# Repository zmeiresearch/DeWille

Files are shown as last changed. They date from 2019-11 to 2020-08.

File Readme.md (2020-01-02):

# DeWille - A modular Audio DAC platform

DeWille is designed to be a set of building blocks for audio DACs. Currently, the following 'blocks' are planned:
* A Base board - Power supplies, interconnects, physical board support
* A Control board - Input selection, reclocking, other digital signal processing
* A PCM1792 DAC board
* An I/V converter board

## Features:
### Inputs/Outputs and interface
* Supports multiple input and output formats:
  * I2S, Left-justified and right-justified PCM
  * S/PDIF, optical and coaxial
  * (Maybe) DSD
* Supports at least 24-bit@192kHz
* Configurable asynchronous reclocking with a FIFO
* Provision for USB support based on either XMOS or Amanero COTS board 
* Provision for Bluetooth audio support
* Provision for playback via WiFi
* Provision for an (oled?) display

### Analog side
* DAC section based on PCM1792
* Supports DAC Mono mode
* Supports PCM1792(4) in NOS mode (inspired by DDAC)
* CCS for PCM1792 Iref
* Supports multiple I/V Converters
* Low-noise power supply for both analog and digital sections

## Design considerations

### Control board
The control board is by far the most complex one in the set. It implements input selection, reclocking as well as all
the signal conversion and processing required to drive the DACs. Several distinct components work together to do this 
- an FPGA, a clock generator block and an MCU module. All the blocks are connected to each other via an SPI bus, with 
the MCU acting as master. The SPI bus also connects to the two DAC boards, allowing on-the-fly reconfiguration as 
required.

#### Hardware Design
* **FPGA**
The FPGA is the one actually doing all the signal manipulation and transformation work. It takes I2S data (PCM and DSD
planned for the future), does the actual reclocking (if told to do so) and outputs I2S (DSD planned for the future) to
the two separate DAC board.

The choice of an FPGA has been a difficult one. First and foremost, an SMD(QFP) package is a must. I have no problem
hand-soldering 0402 components, but I have neither the equipment nor the expertise to handle BGAs reliably. This 
alone limits the choice to basically Xilinx Spartan 3 and some Lattice families. (Intel and Microchip not considered
for different reasons). With ISE 14.7 the last one supporting Spartan 3 and the family NRND for new designs in general
I settled on Lattice, LFXP2-8E-5TN144 in particular. MachXO2 is also an option for a future redesign.

There is an on-board 8-bit wide SRAM chip, with a maximal capacity of 8MBit. Possiblity for a future update is either 
increasing the SRAM size (larger buffer) or increasing the datapath width (better throughput/lower latency).

The FPGA can also be programmed and debugged using the integrated FT2232 interface or the standard Lattice JTAG
connector. If using the FT2232, the second channel is connected to two FPGA pins that could implement a debug UART.

* **Clock generator**
The clock generator block is implemented with two oscillators (at 24.576MHz and 22.5792MHz) and an Si5344 multiplexer,
jitter reduction and clock output buffer circuit. Two of the clock outputs go directly to the DAC boards via either 
the pin header or a dedicated SMA interconnect, while the third is distributed to the FPGA to drive the reclocking 
internally. This clock arrangement is guaranteed to introduce a phase margin between the master clock and the bit/data
clock, but the PCM1794(2) and, in theory, all other DACs that require a System/Master clock do not need a specific 
relation between the two, as long as it remains a fixed one.
Regular oscillators are used rather than TCXOs because the actual frequency and long term drift are not that important 
to the sound quality and the Si5344 performance dominates the short-term jitter performance 

Possibility for a future enchancement is to also route the SCK input from the two I2S inputs to the remaining two
Si5344 inputs to allow source-synchronous operation as well.

* **MCU**
A ESP32-DevKit module was selected for the main MCU. The rationale to use an off-the-shelf MCU module is two-fold.
_First,_ by using an COTS hardware module with a well-established and easy to use software ecosystem behind it, I'll
be able to focus on the signal processing part of the project.
_Second,_ it will be much easier to implement other functionality in the future - OTA updates, including the FPGA 
bitstream, WiFi streaming, Alexa/Google home integration, etc.

* **Power Supply**
The control board takes a single, 5V regulated power supply. There is an on-board protection by means of a polyfuse
and a 6.8V Transil. This is powering a total of 6 voltage regulators:
  * +3V3_IO and +3V3_FPGA -  used for FPGA I/O ports, Debug/Program USB and on-board LEDs
  * +1V2_FPGA - FPGA Core supply
  * +3V3_CLKOUT - Clock outputs of Si5344
  * +3V3_VDDACLK and +1V8VDDCLK - analog and digital sections of Si5344 respectively
  * +3v3_VDDOSC - the two crystal oscillators
  * The on-module voltage regulator in the ESP32 module.

### DAC PCM1794(2)

### Base Board
The base board is responsible for physically carying the different modules together, connecting them electrically and
providing all the required power supplies. In addition, it implements input signal galvanic isolation to limit the harm
in case of failure of signal sources.

* **Power supply**
The base board takes a 220/110VAC mains supply and has two separate sets of transformers. Either 50VAC toroidal power
transformers or PCB-mounted sealed ones can be used. One of the transformers is providing the +5V regulated supply
necessary for the digital part of the schematic, while the other provides a +/- 15V supply.

All three +5V power supplies are filtered and regulated using a hybrid capacitance multiplier/regulator circut. In
addition, there are also two 3.3V regulators for the input galvanic isolators - an LDO for the 'in' side and a 
DC-DC for the 'out' side.

### I to V module
**WiP/TBD.** Assumed to have the same dimensions as the DAC module while creating the Base board.

## FAQ
* **Is DeWille HiFi/Audiophile grade?**
  No. It will just sound good.
* **Where does the name DeWille come from?**
  It was inspired by a [Frey Wille](https://www.freywille.com) scharf that happened to be around while thinking about
  a name for the project.

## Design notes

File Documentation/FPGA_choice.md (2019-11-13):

Requirements:
To be hand-solderable (i.e. no BGA!)
At least 70 IOs (40 IOs for 1MB/16bit RAM, 5 for MCU interface, 4 audio interfaces x 4 IOs each, 5 misc)
Development tools to be easily available.

Initial requirements opted for a much smaller pin count, as external RAM was not required. Choice went to LCMXO2-1200 in a 32-pin QFN package. It proved impossible to find any documentation listing pinouts, will all references either dead or requiring to install Lattice Diamond. 

After re-evaluating the requirements, it was decided to include an external RAM memory for a FIFO inplementation with a sufficient depth. This bumped the requirements for pin count to 70I/Os at least, as 40 extra lanes were required and requiring additional logic gates for the implementation as well. Thus, a Xilinx XC3S100 in a TQFP-100 package was selected. 

However, Spartan 3 is supported only by ISE 14.7, which, in turn is not supported on Win10. All the parts that are supported by the newer toolset appear to be BGA, bringing back the preference to Lattice (Intel out of question due to bad sentiment). So far, LFXP2-8E-5TN144C seems to be the winner, offering a good balance between logic density, timing and price

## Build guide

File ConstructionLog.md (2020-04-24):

# This is an annotated account of the build&construction activities around DeWille

## 26-Nov-2019
*DeWille_Control_Rev_1_0* and *DAC_PCM1794_Rev1_0*, rev. #7dc6edd, sent to 
[SeeedStudio](https://www.seeedstudio.com/fusion_pcb.html) for fabrication. Total cost is $74.20:
* $4.90 for 10 pcs of DAC_PCM1794
* $49.90 for 10pcs of DeWille_Control
* $19.40 shipping

## 13-Dec-2019
Parts for first two prototypes ordered from [Comet](http://www.comet.bg) and [Mouser](http://www.mouser.bg)

## 17-Dec-2019
Parts arrived

## 02-Jan-2020
Control and DAC Boards arrived
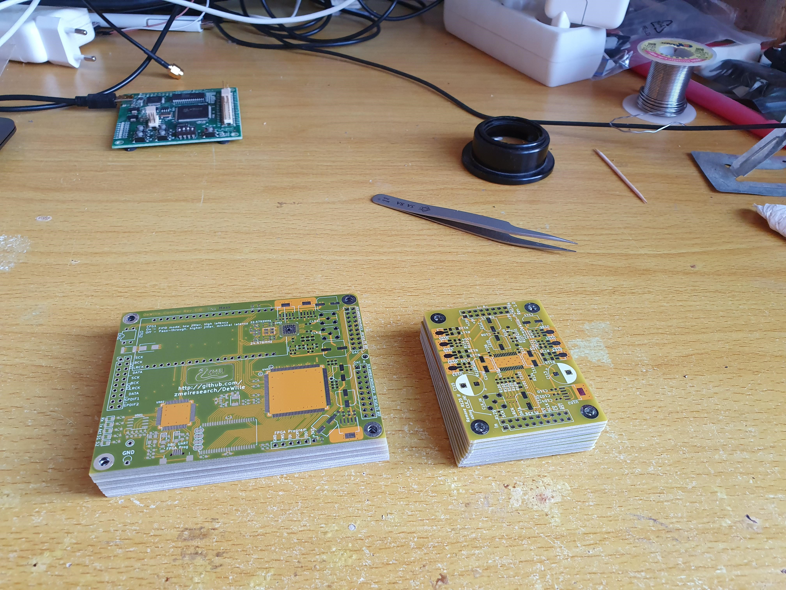
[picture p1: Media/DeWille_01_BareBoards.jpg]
Bare Boards


## 08-Jan-2020
Started soldering one Control board.
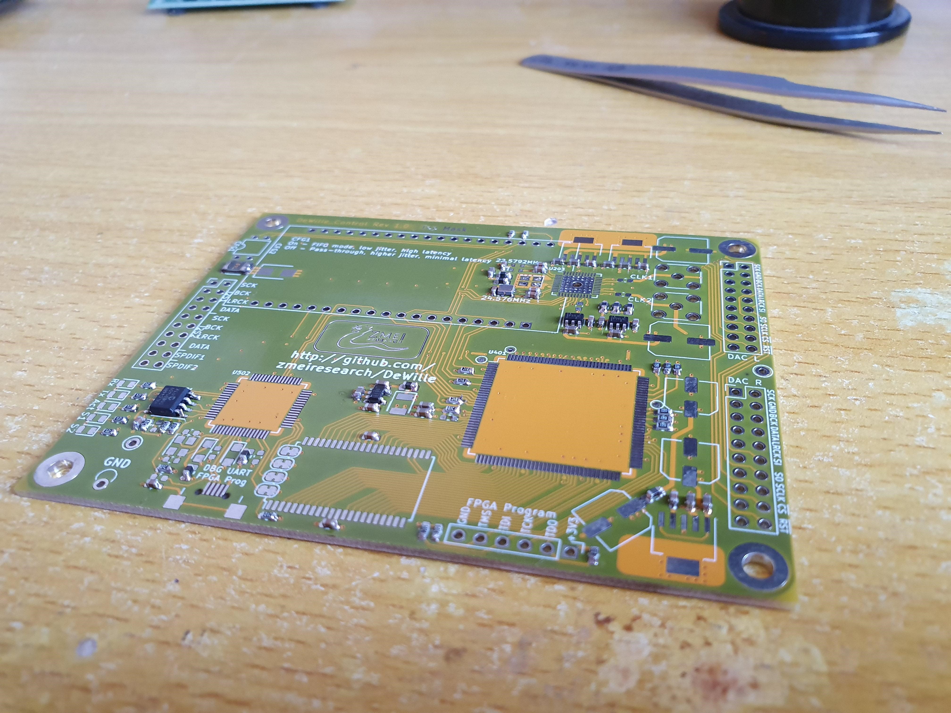
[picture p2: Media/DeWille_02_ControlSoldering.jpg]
Control Soldering


## 09-Jan-2020
One BaseBoard sent to [Selectra](http://www.selectrapcb.com) for fabrication

## 11-Jan-2020
Control board soldering complete, with the exception of the FPGA, the Si5344 and the non-washable components (SMA 
connectors and DIP switces). Applied power and verified that all supply voltages are correct. Gave a final wash
to the Control board to clean flux residue.

## 12-Jan-2020
Soldered two DAC boards without the DAC chips. Applied power and verified supply voltages.
Soldered the rest of the components on the Control board.
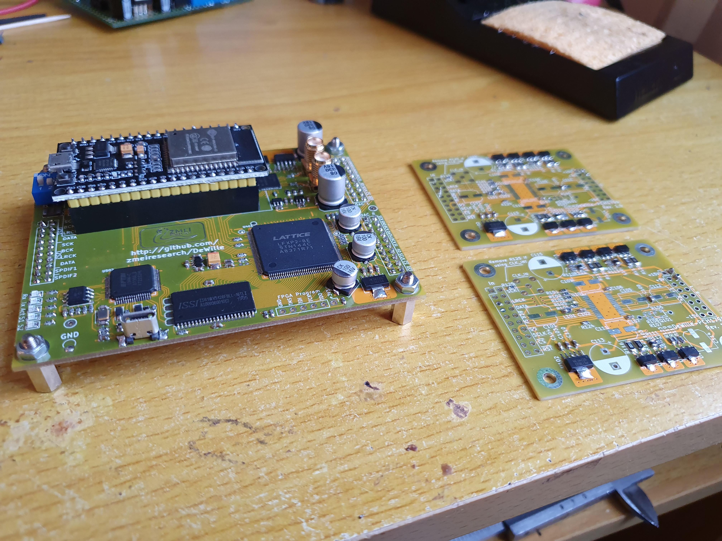
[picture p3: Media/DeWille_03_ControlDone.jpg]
Control done


## 25-Jan-2020
BaseBoard received from PCB house

## 2-Feb-2020
Soldered BaseBoard components without transformers and big filtering caps. Powered the +5V regulator from bench
supply, got +4.6V output due to error in schematic (R217/R220 divider not taken into account when calculating
reference voltage). Changed R212 to 1.5k and got +4.99V output into a 56 Ohm dummy load, verified that regulator
is stable with scope and left it for ~2 hours. With a 6.6 Ohm load(little less than 1A current) and no heat-sink,
the regulator transistor experienced a non-destructive thermal runaway (but the output voltage increased, so 
it may have potentially damaged the rest of the circuit) - probably need to reconsider the topology for later.

Because of the above, decided to use the analog supplies in capacitance multiplier mode rather than regulator, so 
removed U201, U202 and the resistors around them.
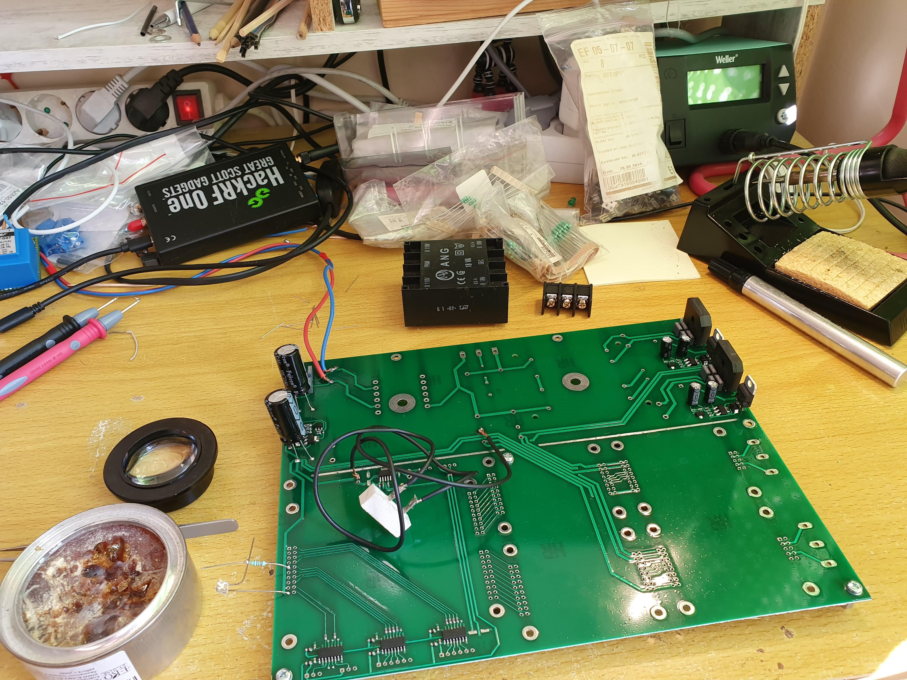
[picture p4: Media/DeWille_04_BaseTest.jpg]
Base test


## 5-Apr-2020
Some work on the software for the Control board:
 * Settled on using the Espressif-supplied version of FreeRTOS along with [PlatformIO](https://platformio.org/) 
 as a base for the software.
 * Implemented a (mostly) platform-independent logger and routed it through the secondary UART of FT2232
 * Implemented a SPI bus arbitrator, to allow multiple components to communicate with the multiple slaves on the
 SPI bus.
 * Added Si553x-specific pseudo-driver that allow read/write of specific registers and bulk set-up based on. 
 [ClockBuilderPro](https://www.silabs.com/products/development-tools/software/clockbuilder-pro-software) exports
 * Added a small script (SiMerge.py) to automatically merge multiple CBP exports into a single file.

After some trial&error, Si5344 started outputting clock signals. Next I'm shifting to the FPGA to try and get some
actual audio data going.

## 20-Apr-2020
After spending some time in Lattice Diamond, I've decided to switch as much as possible to an open/free toolset. All
FPGA modules will be developed in simulation, using Icarus [Verilog](http://iverilog.icarus.com/) &
[GTKWave](http://gtkwave.sourceforge.net/). Only the final synthesis and verification will be done within Diamond (or
another tool if/when the FPGA is changed).
So far, a dummy (as in not doing much) SPI slave module is implemented, along with a testbench and support
infrastructure - I am able to execute the testbench and check the signals/data visually in a single command

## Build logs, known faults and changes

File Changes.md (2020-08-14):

# Future changes

## DAC_PCM1794_Rev1_0
* Change SMA connector with bigger pads
* Polygon fill on the top layer (better color!)
* Add GND and power testpads
* Consider strategic cuts in the GND polygon to separate GND current flow
* The JFET pin-out has Source and Drain swapped
* The JFET CCS circuit is wrong

## DeWille_Control_Rev_1_0
* Change SMA connector with bigger pads
* Use logo with silk-screen
* Add bottom silk screen
* Remove mask at bottom layer of Si5344
* Align GND bottom left testpad silk
* Polygon fill on the top layer (better color!)
* Change footprint for 2.5x2 oscillators for better solderability
* Change footprint for Si5344 to have longer pads
* Increase via diameter below Si5344
* Add silk text to the two TH testpads - 3.3 and far right GND
* Switch to 30pin ESP32 DevKit
* Add a protection diode + jumper for ESP32. Current ESP board connects Vin
  directly to Vusb, which is convenient during development, allowing stand-
  alone operation, but may possibly damage board and/or computer if power
  is applied on both sides
* Move nCS_FPGA and FGPA_DONE away from the UART0 pins
* Check why RX LED is on when the ESP is transmitting and vice versa
* Increase resistors on Green LEDs
* Move FPGA (and maybe the clock as well) to the other SPI bus so that 
  hardware SPI CS can be used
* Fix the ESP32 symbols mix-up (pin25 duplicated, 36 missing)
* Route nINTR Si5344 output to ESP32 so that status polling is not needed
* Make the Clock chip and power supply heat-sinks larger
* Move CS_DACL away from pin35 - input-only 

## DeWille_Base_Rev_1.0
* The GNDD polygon is not correctly manufactured. Check with PCB house whether
  the issue is with the gerbers or with them
* Add Silkscreen and Zmei Research logo
* Remove silkscreen from Top GND tracks separating transformers and the rest of
  the circuit
* Change big filtering capacitors to snap-in ones
* Mark R220 DNP or change R212 to 1.5k
* Add LEDs indicating power status
* Make input connections for I2S fit the standard XMOS/BT board layouts

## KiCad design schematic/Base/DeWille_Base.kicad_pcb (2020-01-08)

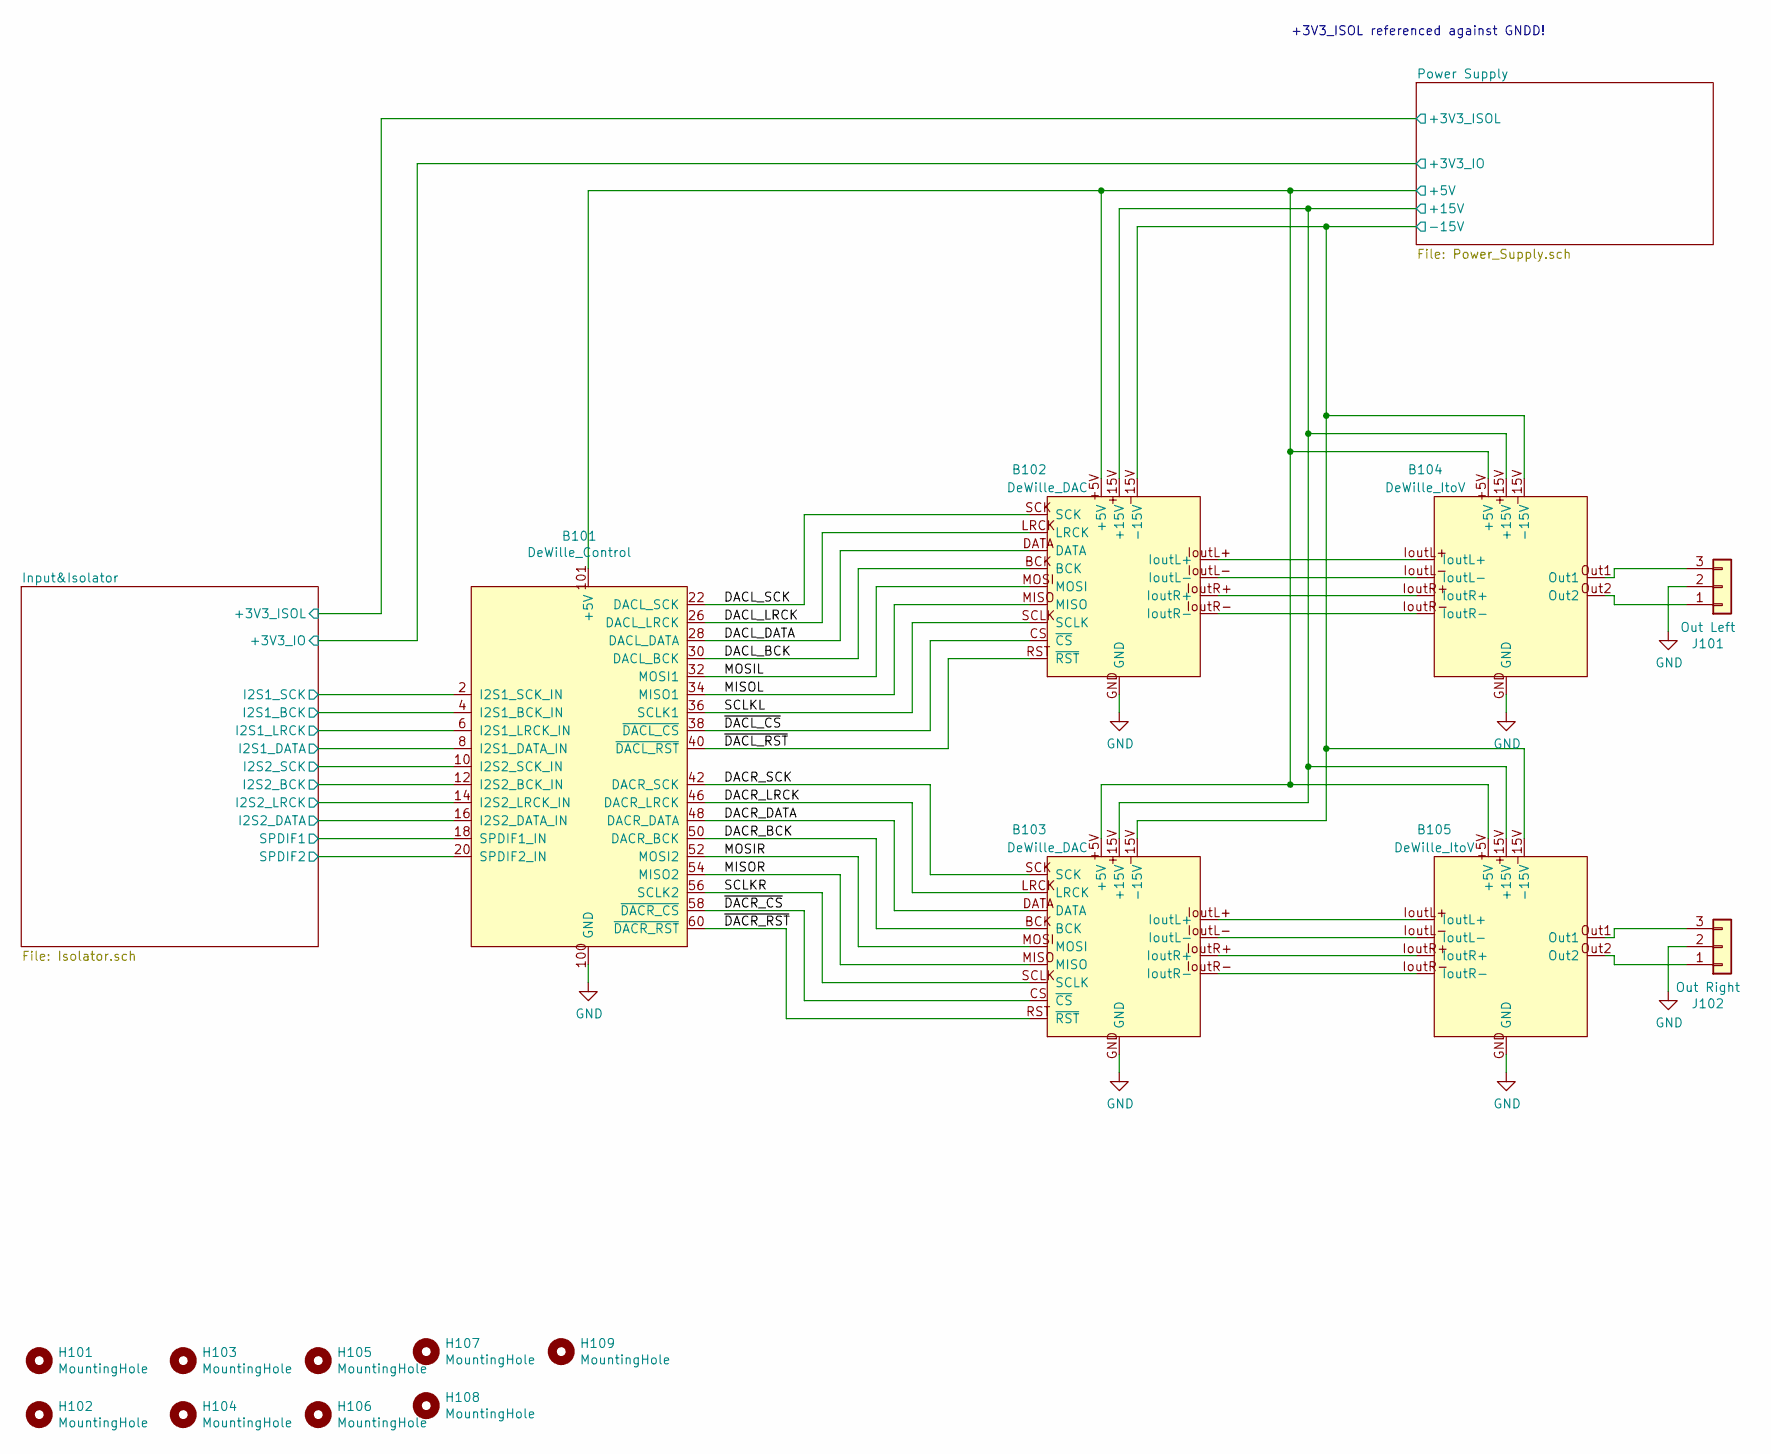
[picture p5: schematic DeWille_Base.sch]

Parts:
B101: DeWille_Control
B102, B103: DeWille_DAC
B104, B105: DeWille_ItoV
H101, H102, H103, H104, H105, H106, H107, H108, H109: MountingHole; MountingHole_3.2mm_M3_Pad
J101: Out Left; TerminalBlock_Dinkle_DT-55-B01X-03_P10.00mm
J102: Out Right; TerminalBlock_Dinkle_DT-55-B01X-03_P10.00mm

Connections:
/DACL_BCK: B101.30 (DACL_BCK), B102.BCK
/DACL_DATA: B101.28 (DACL_DATA), B102.DATA
/DACL_LRCK: B101.26 (DACL_LRCK), B102.LRCK
/DACL_SCK: B101.22 (DACL_SCK), B102.SCK
/DACR_BCK: B101.50 (DACR_BCK), B103.BCK
/DACR_DATA: B101.48 (DACR_DATA), B103.DATA
/DACR_LRCK: B101.46 (DACR_LRCK), B103.LRCK
/DACR_SCK: B101.42 (DACR_SCK), B103.SCK
/Input&Isolator/I2S1_BCK: B101.4 (I2S1_BCK_IN); also elsewhere on the board
/Input&Isolator/I2S1_DATA: B101.8 (I2S1_DATA_IN); also elsewhere on the board
/Input&Isolator/I2S1_LRCK: B101.6 (I2S1_LRCK_IN); also elsewhere on the board
/Input&Isolator/I2S1_SCK: B101.2 (I2S1_SCK_IN); also elsewhere on the board
/Input&Isolator/I2S2_BCK: B101.12 (I2S2_BCK_IN); also elsewhere on the board
/Input&Isolator/I2S2_DATA: B101.16 (I2S2_DATA_IN); also elsewhere on the board
/Input&Isolator/I2S2_LRCK: B101.14 (I2S2_LRCK_IN); also elsewhere on the board
/Input&Isolator/I2S2_SCK: B101.10 (I2S2_SCK_IN); also elsewhere on the board
/Input&Isolator/SPDIF1: B101.18 (SPDIF1_IN); also elsewhere on the board
/Input&Isolator/SPDIF2: B101.20 (SPDIF2_IN); also elsewhere on the board
/MISOL: B101.34 (MISO1), B102.MISO
/MISOR: B101.54 (MISO2), B103.MISO
/MOSIL: B101.32 (MOSI1), B102.MOSI
/MOSIR: B101.52 (MOSI2), B103.MOSI
/Power Supply/+5V: B101.101 (+5V), B102.+5V, B103.+5V, B104.+5V, B105.+5V; also elsewhere on the board
/Power Supply/+15V: B102.+15V, B103.+15V, B104.+15V, B105.+15V; also elsewhere on the board
/Power Supply/-15V: B102.-15V, B103.-15V, B104.-15V, B105.-15V; also elsewhere on the board
/SCLKL: B101.36 (SCLK1), B102.SCLK
/SCLKR: B101.56 (SCLK2), B103.SCLK
/~DACL_CS~: B101.38 (~DACL_CS~), B102.~CS~
/~DACL_RST~: B101.40 (~DACL_RST~), B102.~RST~
/~DACR_CS~: B101.58 (~DACR_CS~), B103.~CS~
/~DACR_RST~: B101.60 (~DACR_RST~), B103.~RST~
GND: B101.100 (GND), B102.GND, B103.GND, B104.GND, B105.GND, J101.2, J102.2; also elsewhere on the board
unnamed: B102.IoutL+, B104.IoutL+
unnamed: B102.IoutL-, B104.IoutL-
unnamed: B102.IoutR+, B104.IoutR+
unnamed: B102.IoutR-, B104.IoutR-
unnamed: B103.IoutL+, B105.IoutL+
unnamed: B103.IoutL-, B105.IoutL-
unnamed: B103.IoutR+, B105.IoutR+
unnamed: B103.IoutR-, B105.IoutR-
unnamed: B104.Out1, J101.3
unnamed: B104.Out2, J101.1
unnamed: B105.Out1, J102.3
unnamed: B105.Out2, J102.1

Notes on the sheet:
+3V3_ISOL referenced against GNDD!

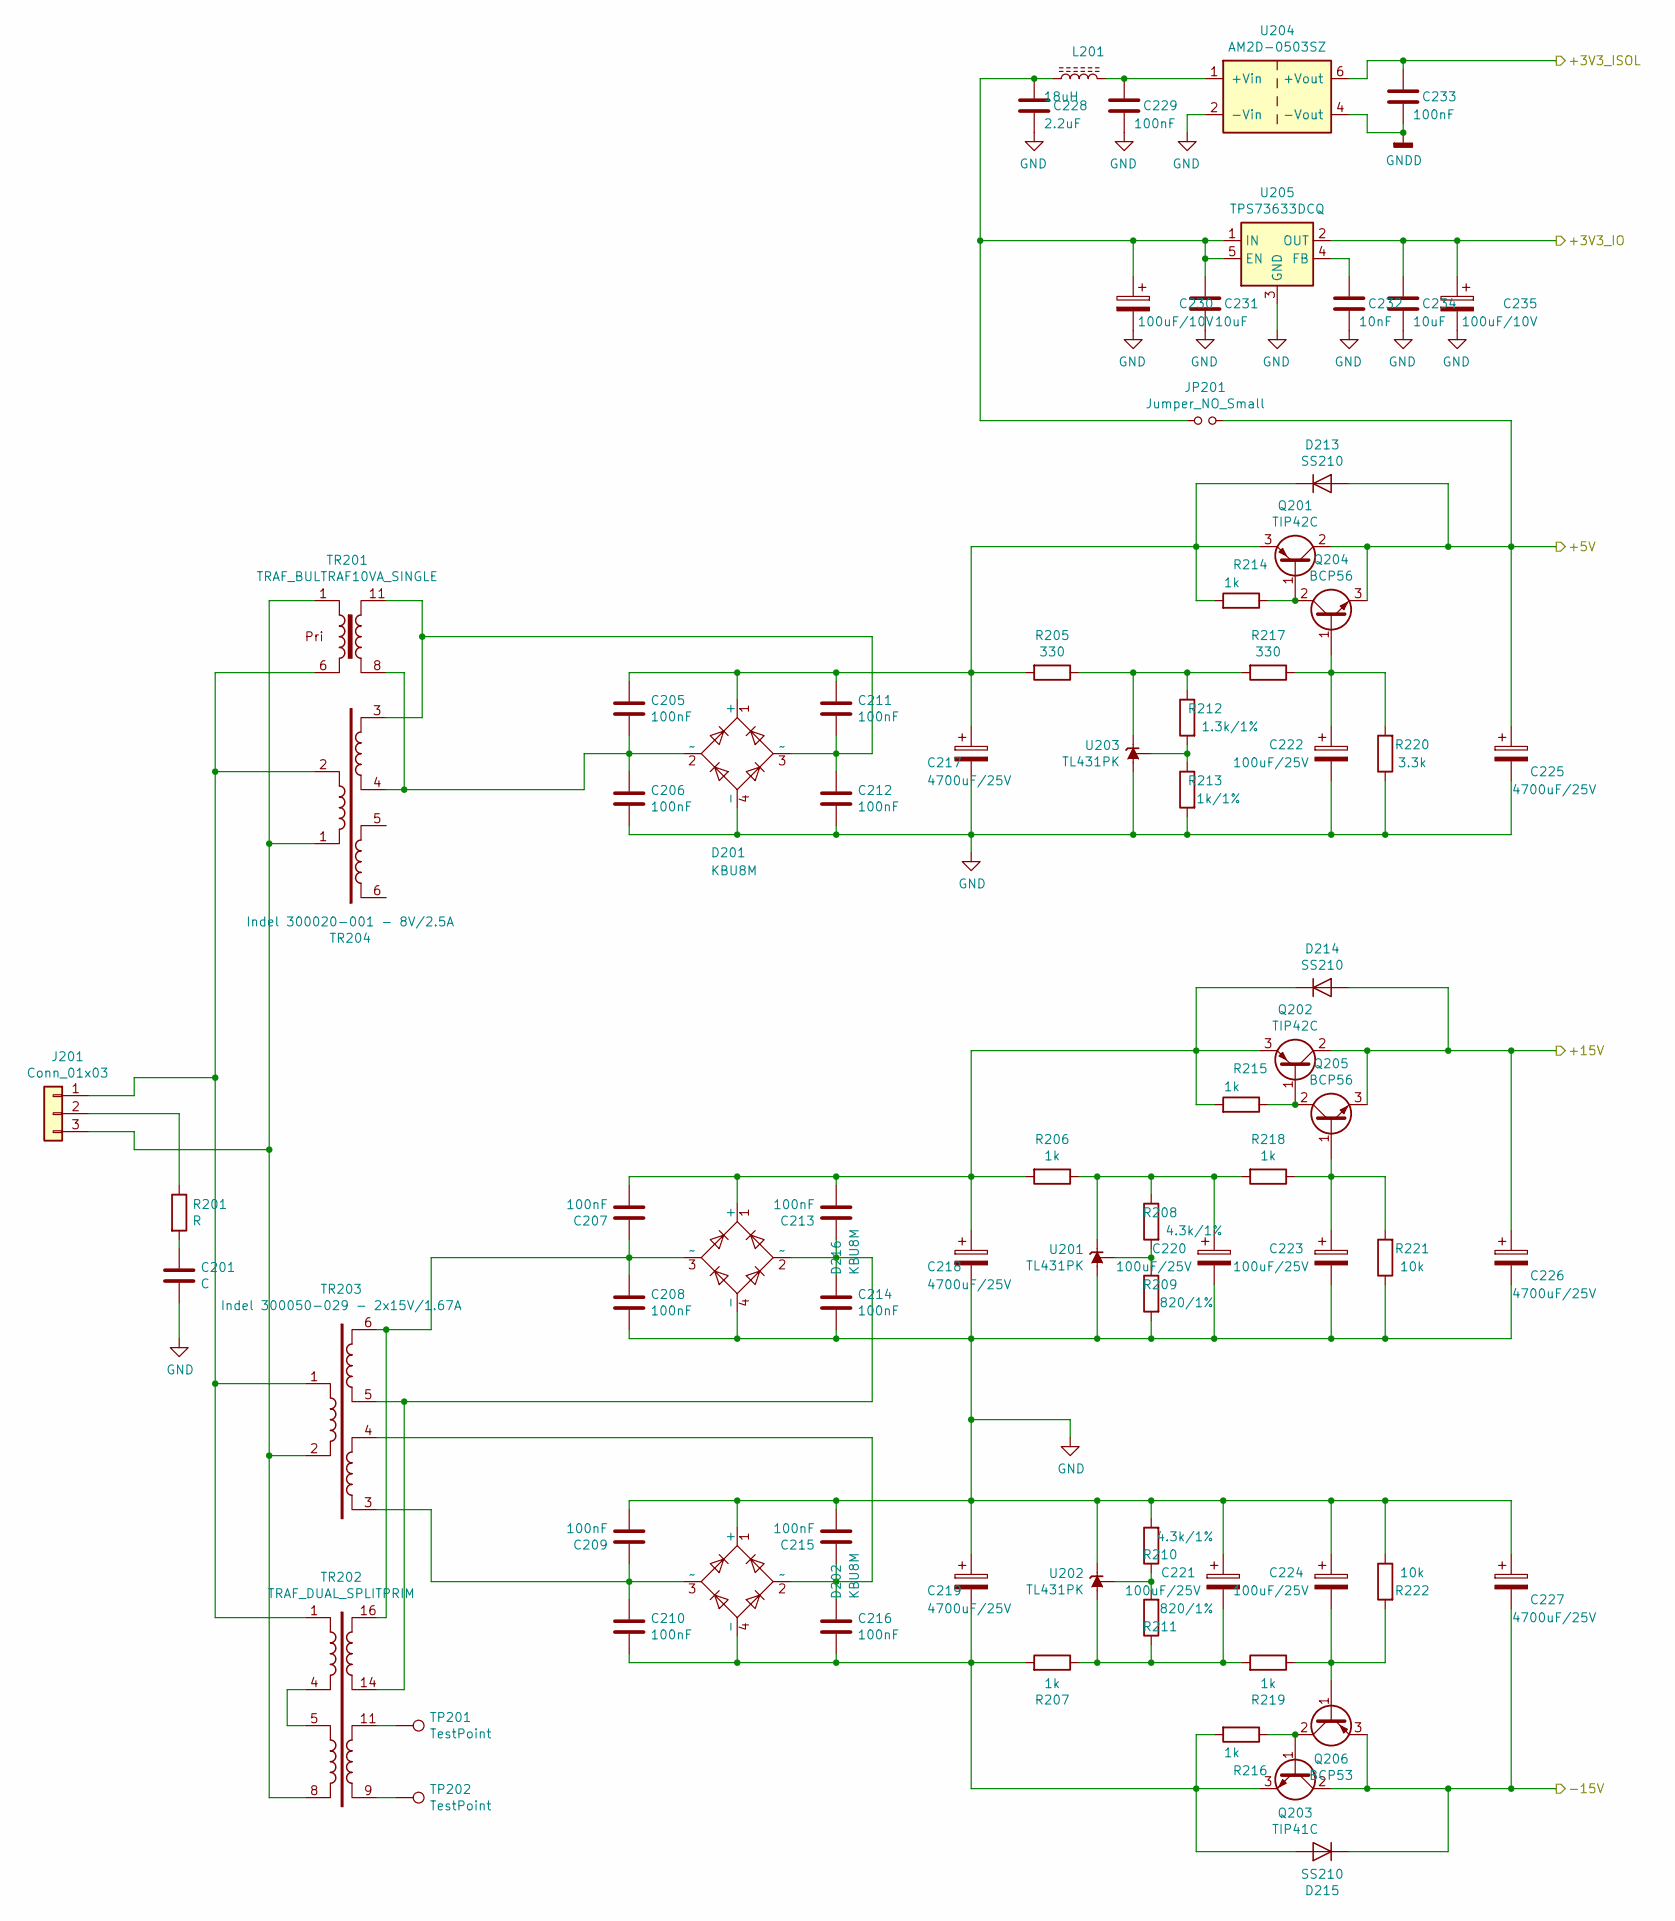
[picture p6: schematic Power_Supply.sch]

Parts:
C201: C; C_Rect_L13.0mm_W6.0mm_P10.00mm_FKS3_FKP3_MKS4
C205, C206, C207, C208, C209, C210, C211, C212, C213, C214, C215, C216: 100nF; C_Rect_L7.2mm_W3.0mm_P5.00mm_FKS2_FKP2_MKS2_MKP2
C217, C218, C219, C225, C226, C227: 4700uF/25V; CP_Radial_D18.0mm_P7.50mm
C220, C221, C222, C223, C224: 100uF/25V; CP_Radial_D8.0mm_P3.50mm
C228: 2.2uF; C_0603_1608Metric
C229, C233: 100nF; C_0603_1608Metric
C230, C235: 100uF/10V; C_Elec_6.3x5.4
C231, C234: 10uF; C_0603_1608Metric
C232: 10nF; C_0603_1608Metric
D201, D202, D216: KBU8M; Diode_Bridge_Vishay_KBU
D213, D214, D215: SS210; D_SMB
J201: Conn_01x03; TerminalBlock_Dinkle_DT-55-B01X-03_P10.00mm
JP201: Jumper_NO_Small; PinSocket_1x02_P2.54mm_Vertical
L201: 18uH; L_Radial_D7.5mm_P3.50mm_Fastron_07P
Q201, Q202: TIP42C; TO-220-3_Vertical
Q203: TIP41C; TO-220-3_Vertical
Q204, Q205: BCP56; SOT-223
Q206: BCP53; SOT-223
R201: R; R_Axial_DIN0207_L6.3mm_D2.5mm_P10.16mm_Horizontal
R205, R217: 330; R_1206_3216Metric
R206, R207, R214, R215, R216, R218, R219: 1k; R_0603_1608Metric
R208, R210: 4.3k/1%; R_0603_1608Metric
R209, R211: 820/1%; R_0603_1608Metric
R212: 1.3k/1%; R_0603_1608Metric
R213: 1k/1%; R_0603_1608Metric
R220: 3.3k; R_1206_3216Metric
R221, R222: 10k; R_0603_1608Metric
TP201, TP202: TestPoint; TestPoint_THTPad_D2.0mm_Drill1.0mm
TR201: TRAF_BULTRAF10VA_SINGLE; TRAF_BULTRAF10VA
TR202: TRAF_DUAL_SPLITPRIM; TRAF_ANG_DUAL_18_24VA
TR203: Indel 300050-029 - 2x15V/1.67A; TRAF_TOROID_50VA
TR204: Indel 300020-001 - 8V/2.5A; TRAF_TOROID_50VA
U201, U202, U203: TL431PK; SOT-89-3
U204: AM2D-0503SZ; Converter_DCDC_AM2D
U205: TPS73633DCQ; SOT-223-6_TabPin3

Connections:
/Input&Isolator/+3V3_IO: C234.2, C235.1, U205.2 (OUT); also elsewhere on the board
/Input&Isolator/+3V3_ISOL: C233.2, U204.6 (+Vout); also elsewhere on the board
/Power Supply/+5V: C225.1, D213.2 (A), JP201.2, Q201.2 (C), Q204.3 (E); also elsewhere on the board
/Power Supply/+15V: C226.1, D214.2 (A), Q202.2 (C), Q205.3 (E); also elsewhere on the board
/Power Supply/-15V: C227.2, D215.1 (K), Q203.2 (C), Q206.3 (E); also elsewhere on the board
GND: C201.2, C206.2, C208.2, C209.2, C212.2, C214.2, C215.2, C217.2, C218.2, C219.1, C220.2, C221.1, C222.2, C223.2, C224.1, C225.2, C226.2, C227.1, C228.1, C229.1, C230.2, C231.1, C232.1, C234.1, C235.2, D201.4 (-), D202.1 (+), D216.4 (-), R209.2, R210.2, R213.2, R220.1, R221.1, R222.1, U201.2 (A), U202.3 (K), U203.2 (A), U204.2 (-Vin), U205.3 (GND); also elsewhere on the board
GNDD: C233.1, U204.4 (-Vout); also elsewhere on the board
unnamed: C201.1, R201.2
unnamed: C205.1, C211.1, C217.1, D201.1 (+), D213.1 (K), Q201.3 (E), R205.2, R214.2
unnamed: C205.2, C206.1, D201.2 (~~), TR201.8, TR204.4
unnamed: C207.1, C208.1, D216.3 (~~), TR202.16, TR203.6
unnamed: C207.2, C213.2, C218.1, D214.1 (K), D216.1 (+), Q202.3 (E), R206.2, R215.2
unnamed: C209.1, C210.1, D202.3 (~~), TR203.3
unnamed: C210.2, C216.2, C219.2, D202.4 (-), D215.2 (A), Q203.3 (E), R207.2, R216.2
unnamed: C211.2, C212.1, D201.3 (~~), TR201.11, TR204.3
unnamed: C213.1, C214.1, D216.2 (~~), TR202.14, TR203.5
unnamed: C215.1, C216.1, D202.2 (~~), TR203.4
unnamed: C220.1, R206.1, R208.1, R218.2, U201.3 (K)
unnamed: C221.2, R207.1, R211.1, R219.2, U202.2 (A)
unnamed: C222.1, Q204.1 (B), R217.1, R220.2
unnamed: C223.1, Q205.1 (B), R218.1, R221.2
unnamed: C224.2, Q206.1 (B), R219.1, R222.2
unnamed: C228.2, C230.1, C231.2, JP201.1, L201.2, U205.1 (IN), U205.5 (EN)
unnamed: C229.2, L201.1, U204.1 (+Vin)
unnamed: C232.2, U205.4 (FB)
unnamed: J201.1, TR201.6, TR202.1, TR203.1, TR204.2
unnamed: J201.2, R201.1
unnamed: J201.3, TR201.1, TR202.8, TR203.2, TR204.1
unnamed: Q201.1 (B), Q204.2 (C), Q204.4 (C), R214.1
unnamed: Q202.1 (B), Q205.2 (C), Q205.4 (C), R215.1
unnamed: Q203.1 (B), Q206.2 (C), Q206.4 (C), R216.1
unnamed: R205.1, R212.1, R217.2, U203.3 (K)
unnamed: R208.2, R209.1, U201.1 (REF)
unnamed: R210.1, R211.2, U202.1 (REF)
unnamed: R212.2, R213.1, U203.1 (REF)
unnamed: TP201.1, TR202.11
unnamed: TP202.1, TR202.9
unnamed: TR202.4, TR202.5

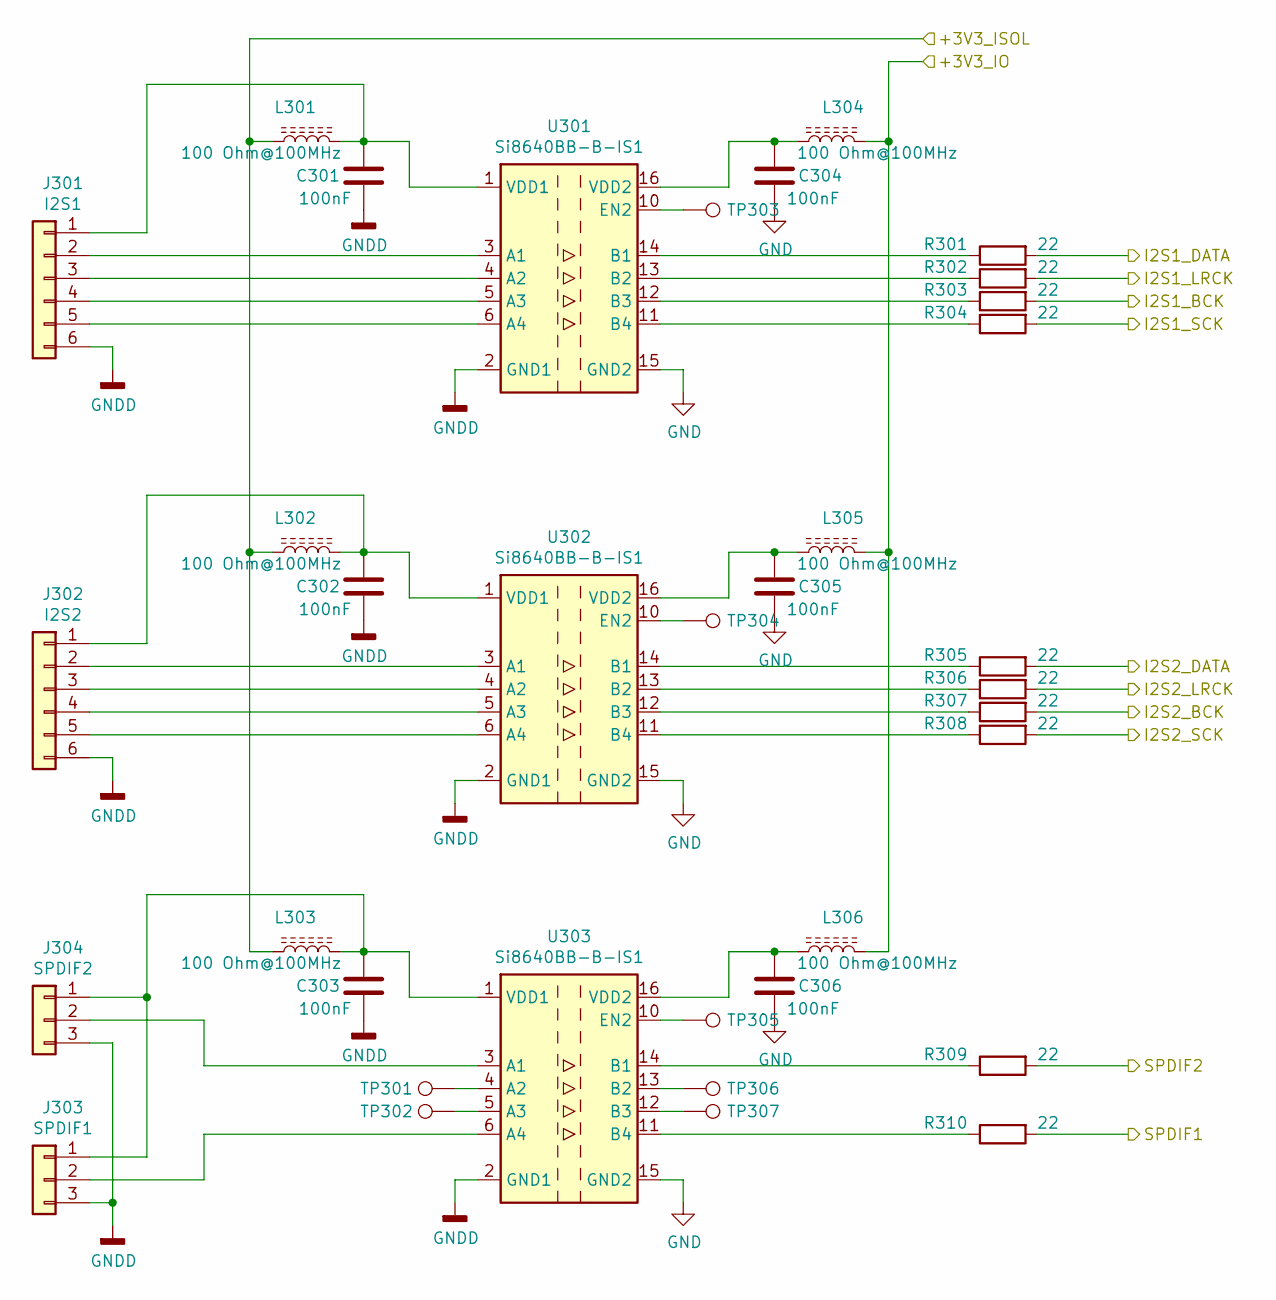
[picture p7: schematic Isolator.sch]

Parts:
C301, C302, C303, C304, C305, C306: 100nF; C_0603_1608Metric
J301: I2S1; PinSocket_1x06_P2.54mm_Vertical
J302: I2S2; PinSocket_1x06_P2.54mm_Vertical
J303: SPDIF1; PinSocket_1x03_P2.54mm_Vertical
J304: SPDIF2; PinSocket_1x03_P2.54mm_Vertical
L301, L302, L303, L304, L305, L306: 100 Ohm@100MHz; L_0805_2012Metric
R301, R302, R303, R304, R305, R306, R307, R308, R309, R310: 22; R_0603_1608Metric
TP301, TP302, TP303, TP304, TP305, TP306, TP307: TestPoint; TestPoint_Pad_D1.0mm
U301, U302, U303: Si8640BB-B-IS1; SOIC-16_3.9x9.9mm_P1.27mm

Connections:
/Input&Isolator/+3V3_IO: L304.1, L305.1, L306.1; also elsewhere on the board
/Input&Isolator/+3V3_ISOL: L301.1, L302.1, L303.1; also elsewhere on the board
/Input&Isolator/I2S1_BCK: R303.2; also elsewhere on the board
/Input&Isolator/I2S1_DATA: R301.2; also elsewhere on the board
/Input&Isolator/I2S1_LRCK: R302.2; also elsewhere on the board
/Input&Isolator/I2S1_SCK: R304.2; also elsewhere on the board
/Input&Isolator/I2S2_BCK: R307.2; also elsewhere on the board
/Input&Isolator/I2S2_DATA: R305.2; also elsewhere on the board
/Input&Isolator/I2S2_LRCK: R306.2; also elsewhere on the board
/Input&Isolator/I2S2_SCK: R308.2; also elsewhere on the board
/Input&Isolator/SPDIF1: R310.2; also elsewhere on the board
/Input&Isolator/SPDIF2: R309.2; also elsewhere on the board
GND: C304.1, C305.1, C306.1, U301.9 (GND2), U301.15 (GND2), U302.9 (GND2), U302.15 (GND2), U303.9 (GND2), U303.15 (GND2); also elsewhere on the board
GNDD: C301.1, C302.1, C303.1, J301.6, J302.6, J303.3, J304.3, U301.2 (GND1), U301.8 (GND1), U302.2 (GND1), U302.8 (GND1), U303.2 (GND1), U303.8 (GND1); also elsewhere on the board
unnamed: C301.2, J301.1, L301.2, U301.1 (VDD1)
unnamed: C302.2, J302.1, L302.2, U302.1 (VDD1)
unnamed: C303.2, J303.1, J304.1, L303.2, U303.1 (VDD1)
unnamed: C304.2, L304.2, U301.16 (VDD2)
unnamed: C305.2, L305.2, U302.16 (VDD2)
unnamed: C306.2, L306.2, U303.16 (VDD2)
unnamed: J301.2, U301.3 (A1)
unnamed: J301.3, U301.4 (A2)
unnamed: J301.4, U301.5 (A3)
unnamed: J301.5, U301.6 (A4)
unnamed: J302.2, U302.3 (A1)
unnamed: J302.3, U302.4 (A2)
unnamed: J302.4, U302.5 (A3)
unnamed: J302.5, U302.6 (A4)
unnamed: J303.2, U303.6 (A4)
unnamed: J304.2, U303.3 (A1)
unnamed: R301.1, U301.14 (B1)
unnamed: R302.1, U301.13 (B2)
unnamed: R303.1, U301.12 (B3)
unnamed: R304.1, U301.11 (B4)
unnamed: R305.1, U302.14 (B1)
unnamed: R306.1, U302.13 (B2)
unnamed: R307.1, U302.12 (B3)
unnamed: R308.1, U302.11 (B4)
unnamed: R309.1, U303.14 (B1)
unnamed: R310.1, U303.11 (B4)
unnamed: TP301.1, U303.4 (A2)
unnamed: TP302.1, U303.5 (A3)
unnamed: TP303.1, U301.10 (EN2)
unnamed: TP304.1, U302.10 (EN2)
unnamed: TP305.1, U303.10 (EN2)
unnamed: TP306.1, U303.13 (B2)
unnamed: TP307.1, U303.12 (B3)

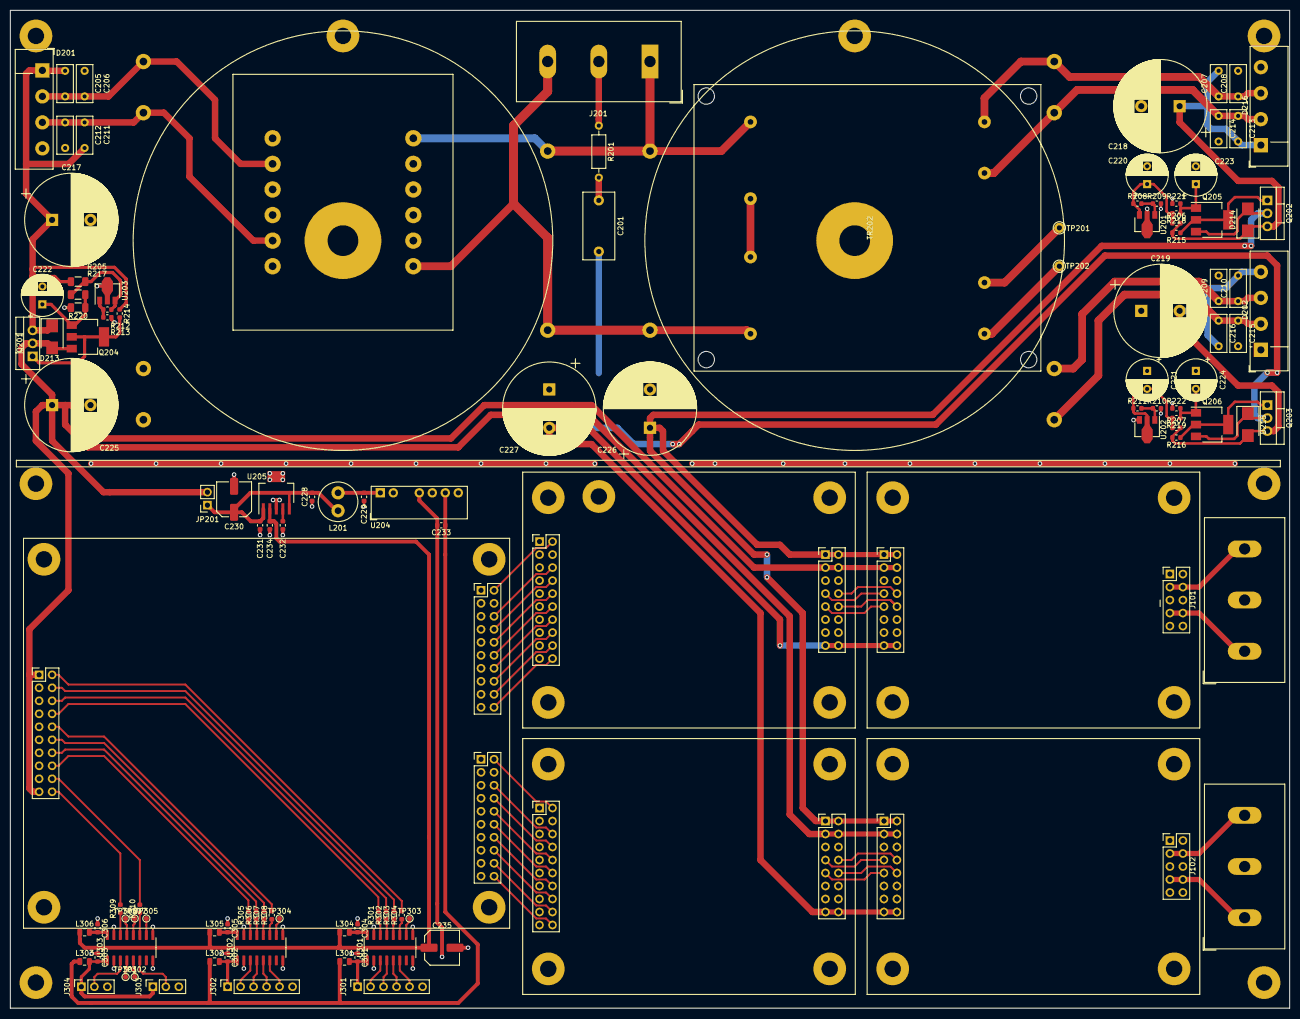
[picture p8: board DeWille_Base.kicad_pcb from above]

Board: 2 copper layers, 250.0 x 195.0 mm, 129 parts (0 on the bottom side), 111 nets.

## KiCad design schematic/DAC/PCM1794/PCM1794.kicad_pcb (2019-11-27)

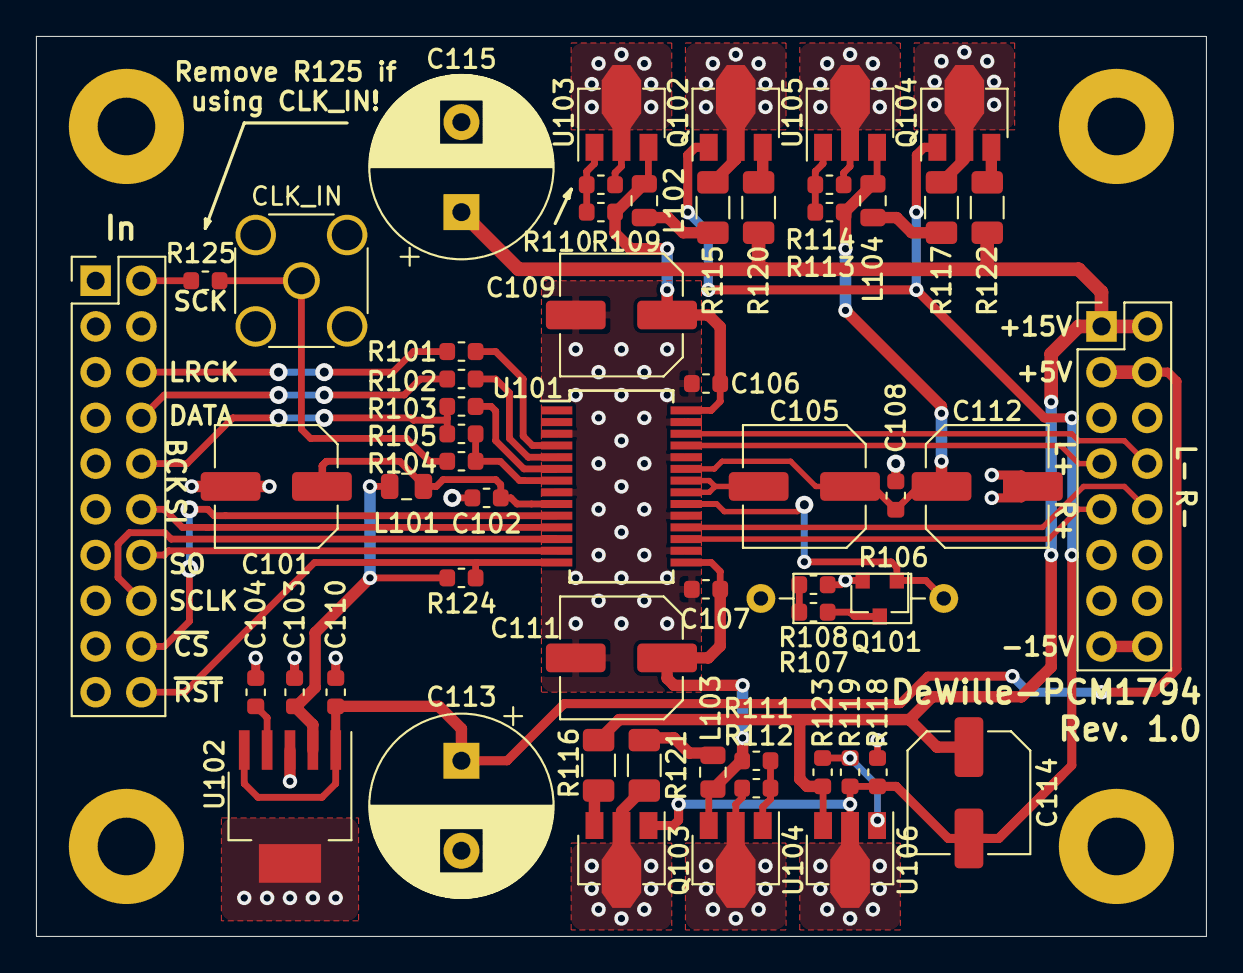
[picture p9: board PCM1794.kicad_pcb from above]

Board: 2 copper layers, 65.0 x 50.0 mm, 62 parts (1 on the bottom side), 46 nets.

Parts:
C101, C105, C109, C111, C112, C114: 100uF/10V; C_Elec_6.3x7.7
C102, C106, C107, C108: 100nF; C_0603_1608Metric
C103, C110: 10uF; C_0603_1608Metric
C104: 10nF; C_0603_1608Metric
C113, C115: 1000uF/16V; CP_Radial_D10.0mm_P5.00mm
H101, H102, H103, H104: MountingHole; MountingHole_3.2mm_M3_Pad
J101: In; PinHeader_2x10_P2.54mm_Vertical
J102: Out; PinHeader_2x08_P2.54mm_Vertical
J103: SMA F ST PCB; SMA_Amphenol_132134_Vertical
L101: 10 Ohm@100MHz; L_0805_2012Metric
L102, L103, L104: 100 Ohm@100MHz; L_0805_2012Metric
Q101: 2SK208; SOT-23
Q102, Q103, Q104: BCX53-16; SOT-89-3
R101, R102, R103, R104, R108, R125: 0; R_0603_1608Metric
R105: DNP; R_0603_1608Metric
R106: DNP/6K; R_Axial_DIN0207_L6.3mm_D2.5mm_P10.16mm_Horizontal
R107: 470; R_0603_1608Metric
R109, R110, R111, R112, R113, R114, R119, R123: 1k/1%; R_0603_1608Metric
R115, R116, R117: 100; R_1206_3216Metric
R118: 4.7k; R_0603_1608Metric
R120, R121, R122: 150; R_1206_3216Metric
R124: 10k; R_0603_1608Metric
U101: PCM1792A; SSOP-28_5.3x10.2mm_P0.65mm
U102: TPS73633DCQ; SOT-223-6_TabPin3
U103, U104, U105, U106: TL431PK; SOT-89-3
U107: Logo; Zmei-logo-small-inverted_silk

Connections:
/+5V: C110.2, C113.1, J102.3, J102.4, U102.1, U102.5
/+15VA: C114.1, C115.1, J102.1, J102.2, R120.1, R121.1, R122.1, R123.1, U106.3
/-15VA: J102.15, J102.16
/BCK: J101.10, R103.2, R105.2
/DATA: J101.8, R102.2
/IoutL+: J102.7, U101.25
/IoutL-: J102.8, U101.26
/IoutR+: J102.9, U101.17
/IoutR-: J102.10, U101.18
/LRCK: J101.6, R101.2
/MISO: J101.14, U101.13
/MOSI: J101.12, U101.11
/SCK: J103.1, R104.2, R125.1
/SCLK: J101.16, U101.12
/~CS~: J101.18, U101.10
/~RST~: J101.20, R124.1, U101.14
GND: C101.2, C102.2, C103.1, C104.1, C106.2, C107.2, C108.2, C109.2, C110.1, C111.2, C112.2, C113.2, C115.2, J101.1, J101.3, J101.4, J101.5, J101.7, J101.9, J101.11, J101.13, J101.15, J101.17, J101.19, J102.5, J102.6, J102.11, J102.12, J102.13, J102.14, J103.2, Q101.2, R106.2, R108.2, R110.2, R112.2, R114.2, R118.2, U101.3, U101.8, U101.16, U101.19, U101.24, U101.27, U102.3, U103.2, U104.2, U105.2
unnamed: C101.1, C102.1, L101.2, U101.9
unnamed: C103.2, L101.1, R124.2, U102.2
unnamed: C104.2, U102.4
unnamed: C105.1, C108.1, C112.1, L104.1, R113.1, U101.23, U105.3
unnamed: C105.2, U101.21, U101.22
unnamed: C106.1, C109.1, L102.1, R109.1, U101.28, U103.3
unnamed: C107.1, C111.1, L103.1, R111.1, U101.15, U104.3
unnamed: C114.2, Q102.1, Q103.1, Q104.1, R118.1, R119.2, U106.2
unnamed: J101.2, R125.2
unnamed: L102.2, R115.2
unnamed: L103.2, R116.2
unnamed: L104.2, R117.2
unnamed: Q101.1, R106.1, U101.20
unnamed: Q101.3, R107.1
unnamed: Q102.2, R115.1
unnamed: Q102.3, R120.2
unnamed: Q103.2, R116.1
unnamed: Q103.3, R121.2
unnamed: Q104.2, R117.1
unnamed: Q104.3, R122.2
unnamed: R101.1, U101.4
unnamed: R102.1, U101.5
unnamed: R103.1, U101.6
unnamed: R104.1, R105.1, U101.7
unnamed: R107.2, R108.1
unnamed: R109.2, R110.1, U103.1
unnamed: R111.2, R112.1, U104.1
unnamed: R113.2, R114.1, U105.1
unnamed: R119.1, R123.2, U106.1

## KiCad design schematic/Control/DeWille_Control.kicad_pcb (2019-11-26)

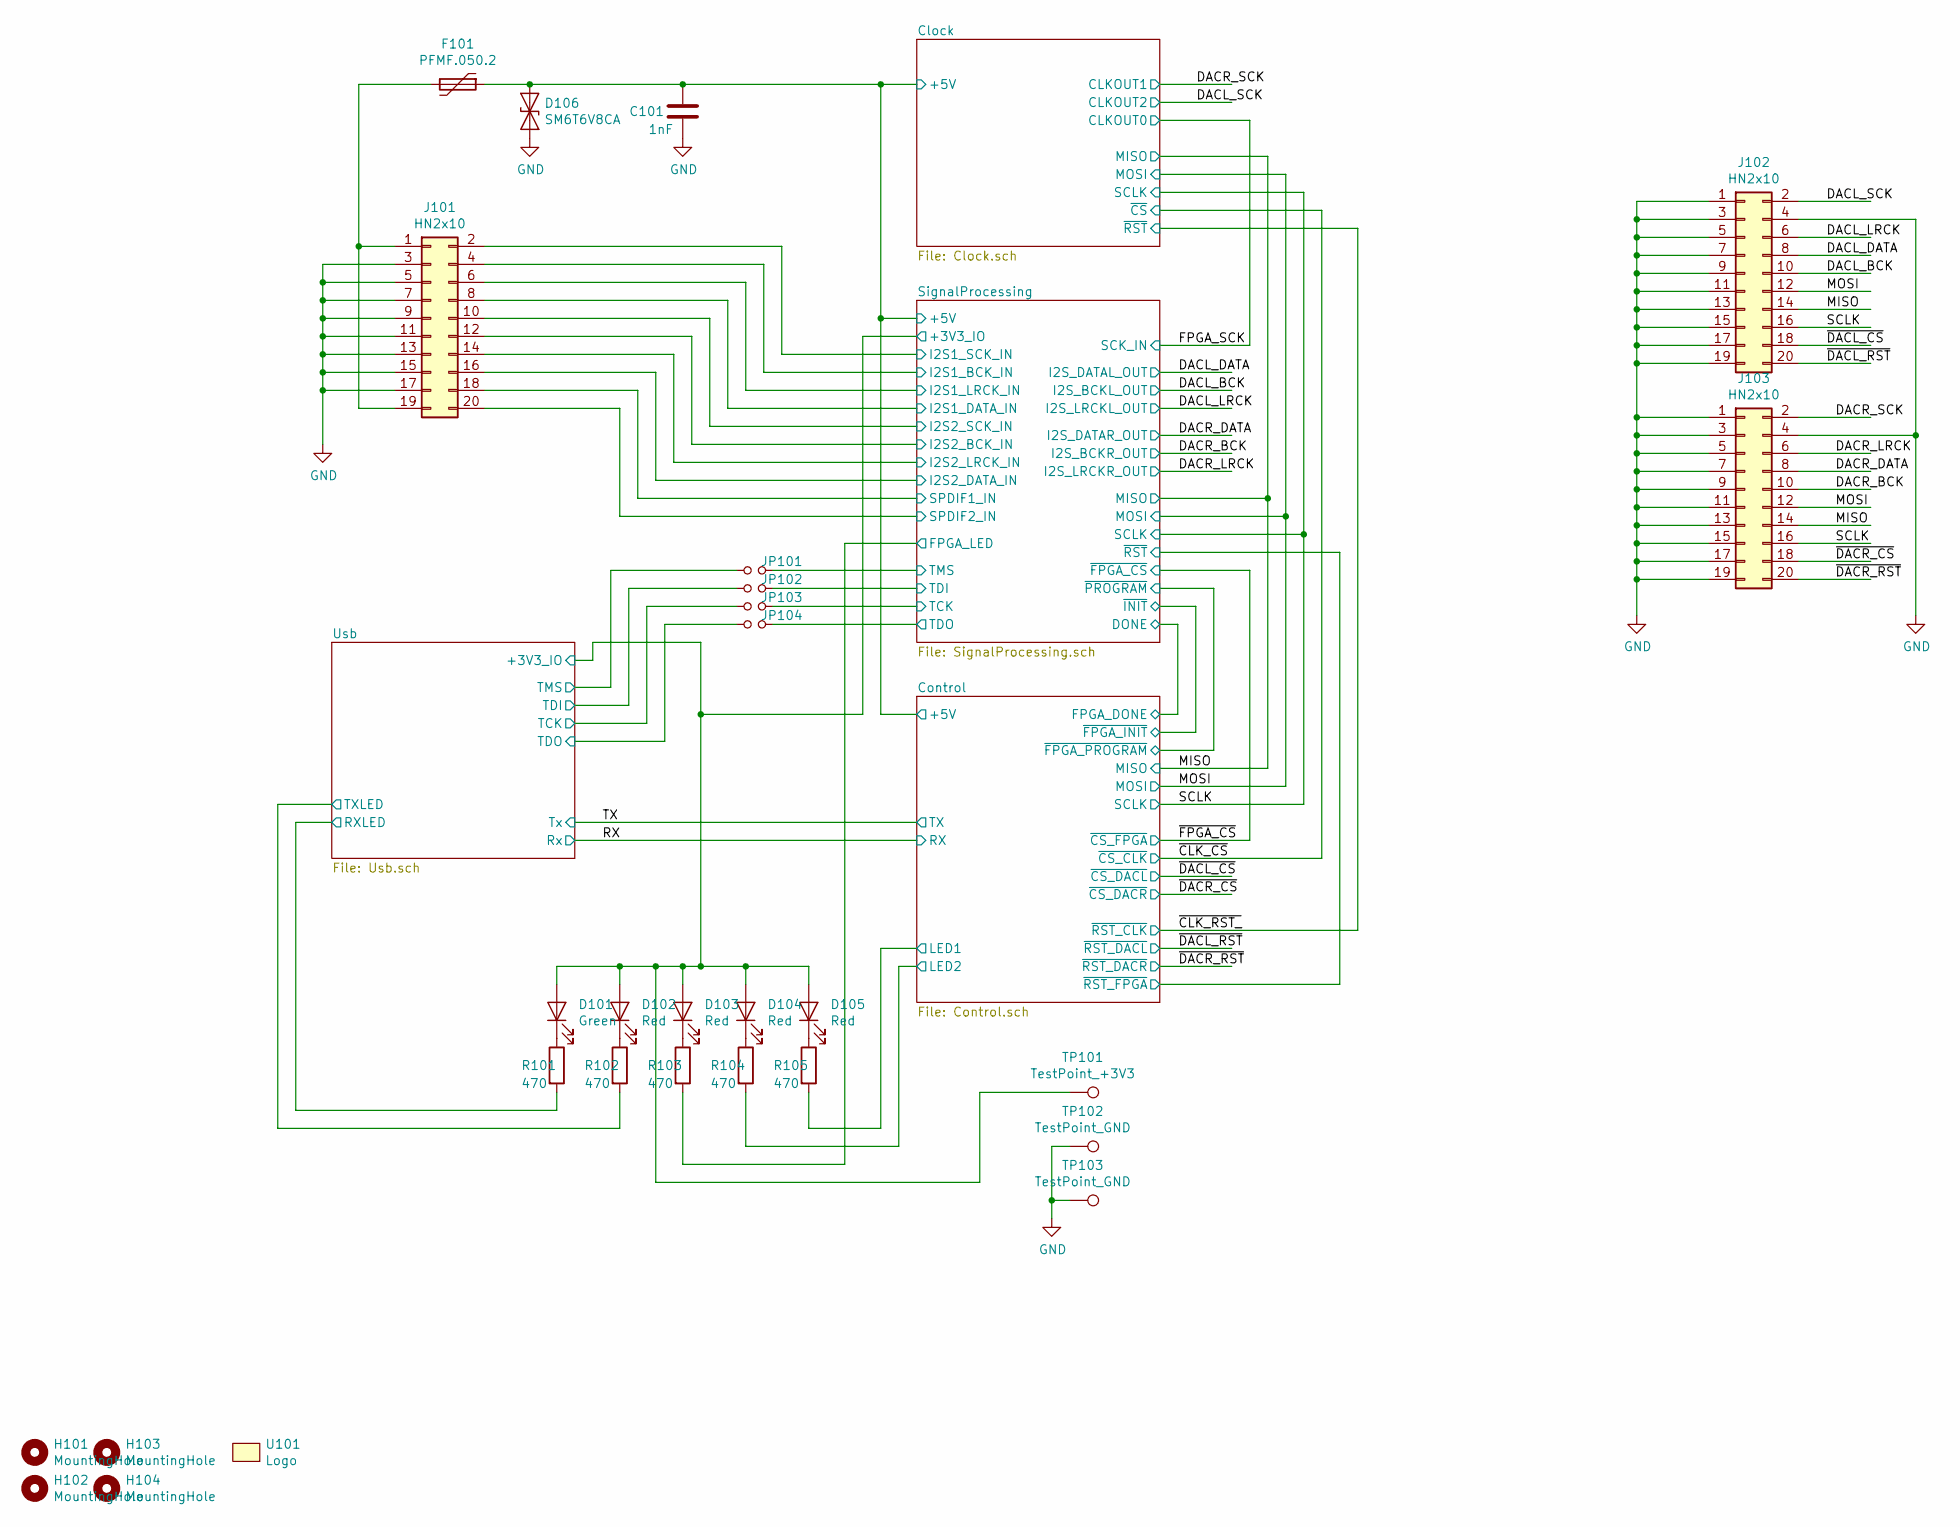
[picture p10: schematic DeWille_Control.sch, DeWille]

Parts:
C101: 1nF; C_0603_1608Metric
D101: Green; LED_0805_2012Metric
D102, D103, D104, D105: Red; LED_0805_2012Metric
D106: SM6T6V8CA; D_SMB
F101: PFMF.050.2; Fuse_1812_4532Metric
H101, H102, H103, H104: MountingHole; MountingHole_3.2mm_M3_Pad
J101, J102, J103: HN2x10; PinHeader_2x10_P2.54mm_Vertical
JP101, JP102, JP103, JP104: SolderJumper-2_P1.3mm_Bridged_RoundedPad1.0x1.5mm
R101, R102, R103, R104, R105: 470; R_0603_1608Metric
TP101: TestPoint_+3V3; TestPoint_THTPad_D2.0mm_Drill1.0mm
TP102, TP103: TestPoint_GND; TestPoint_THTPad_D2.0mm_Drill1.0mm
U101: Logo; Zmei-logo-small-inverted_nosilk

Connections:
/Clock/+5V: C101.2, D106.1 (A1), F101.1; also elsewhere on the board
/Control/LED1: R105.2; also elsewhere on the board
/Control/LED2: R104.2; also elsewhere on the board
/DACL_BCK: J102.10; also elsewhere on the board
/DACL_DATA: J102.8; also elsewhere on the board
/DACL_LRCK: J102.6; also elsewhere on the board
/DACL_SCK: J102.2; also elsewhere on the board
/DACR_BCK: J103.10; also elsewhere on the board
/DACR_DATA: J103.8; also elsewhere on the board
/DACR_LRCK: J103.6; also elsewhere on the board
/DACR_SCK: J103.2; also elsewhere on the board
/MISO: J102.14, J103.14; also elsewhere on the board
/MOSI: J102.12, J103.12; also elsewhere on the board
/SCLK: J102.16, J103.16; also elsewhere on the board
/SignalProcessing/+3V3_IO: D101.2 (A), D102.2 (A), D103.2 (A), D104.2 (A), D105.2 (A), TP101.1; also elsewhere on the board
/SignalProcessing/FPGA_LED: R103.2; also elsewhere on the board
/SignalProcessing/I2S1_BCK_IN: J101.4; also elsewhere on the board
/SignalProcessing/I2S1_DATA_IN: J101.8; also elsewhere on the board
/SignalProcessing/I2S1_LRCK_IN: J101.6; also elsewhere on the board
/SignalProcessing/I2S1_SCK_IN: J101.2; also elsewhere on the board
/SignalProcessing/I2S2_BCK_IN: J101.12; also elsewhere on the board
/SignalProcessing/I2S2_DATA_IN: J101.16; also elsewhere on the board
/SignalProcessing/I2S2_LRCK_IN: J101.14; also elsewhere on the board
/SignalProcessing/I2S2_SCK_IN: J101.10; also elsewhere on the board
/SignalProcessing/SPDIF1_IN: J101.18; also elsewhere on the board
/SignalProcessing/SPDIF2_IN: J101.20; also elsewhere on the board
/SignalProcessing/TCK: JP103.2; also elsewhere on the board
/SignalProcessing/TDI: JP102.2; also elsewhere on the board
/SignalProcessing/TDO: JP104.2; also elsewhere on the board
/SignalProcessing/TMS: JP101.2; also elsewhere on the board
/Usb/RXLED: R101.2; also elsewhere on the board
/Usb/TCK: JP103.1; also elsewhere on the board
/Usb/TDI: JP102.1; also elsewhere on the board
/Usb/TDO: JP104.1; also elsewhere on the board
/Usb/TMS: JP101.1; also elsewhere on the board
/Usb/TXLED: R102.2; also elsewhere on the board
/~DACL_CS~: J102.18; also elsewhere on the board
/~DACL_RST~: J102.20; also elsewhere on the board
/~DACR_CS~: J103.18; also elsewhere on the board
/~DACR_RST~: J103.20; also elsewhere on the board
GND: C101.1, D106.2 (A2), J101.3, J101.5, J101.7, J101.9, J101.11, J101.13, J101.15, J101.17, J102.1, J102.3, J102.4, J102.5, J102.7, J102.9, J102.11, J102.13, J102.15, J102.17, J102.19, J103.1, J103.3, J103.4, J103.5, J103.7, J103.9, J103.11, J103.13, J103.15, J103.17, J103.19, TP102.1, TP103.1; also elsewhere on the board
unnamed: D101.1 (K), R101.1
unnamed: D102.1 (K), R102.1
unnamed: D103.1 (K), R103.1
unnamed: D104.1 (K), R104.1
unnamed: D105.1 (K), R105.1
unnamed: F101.2, J101.1, J101.19

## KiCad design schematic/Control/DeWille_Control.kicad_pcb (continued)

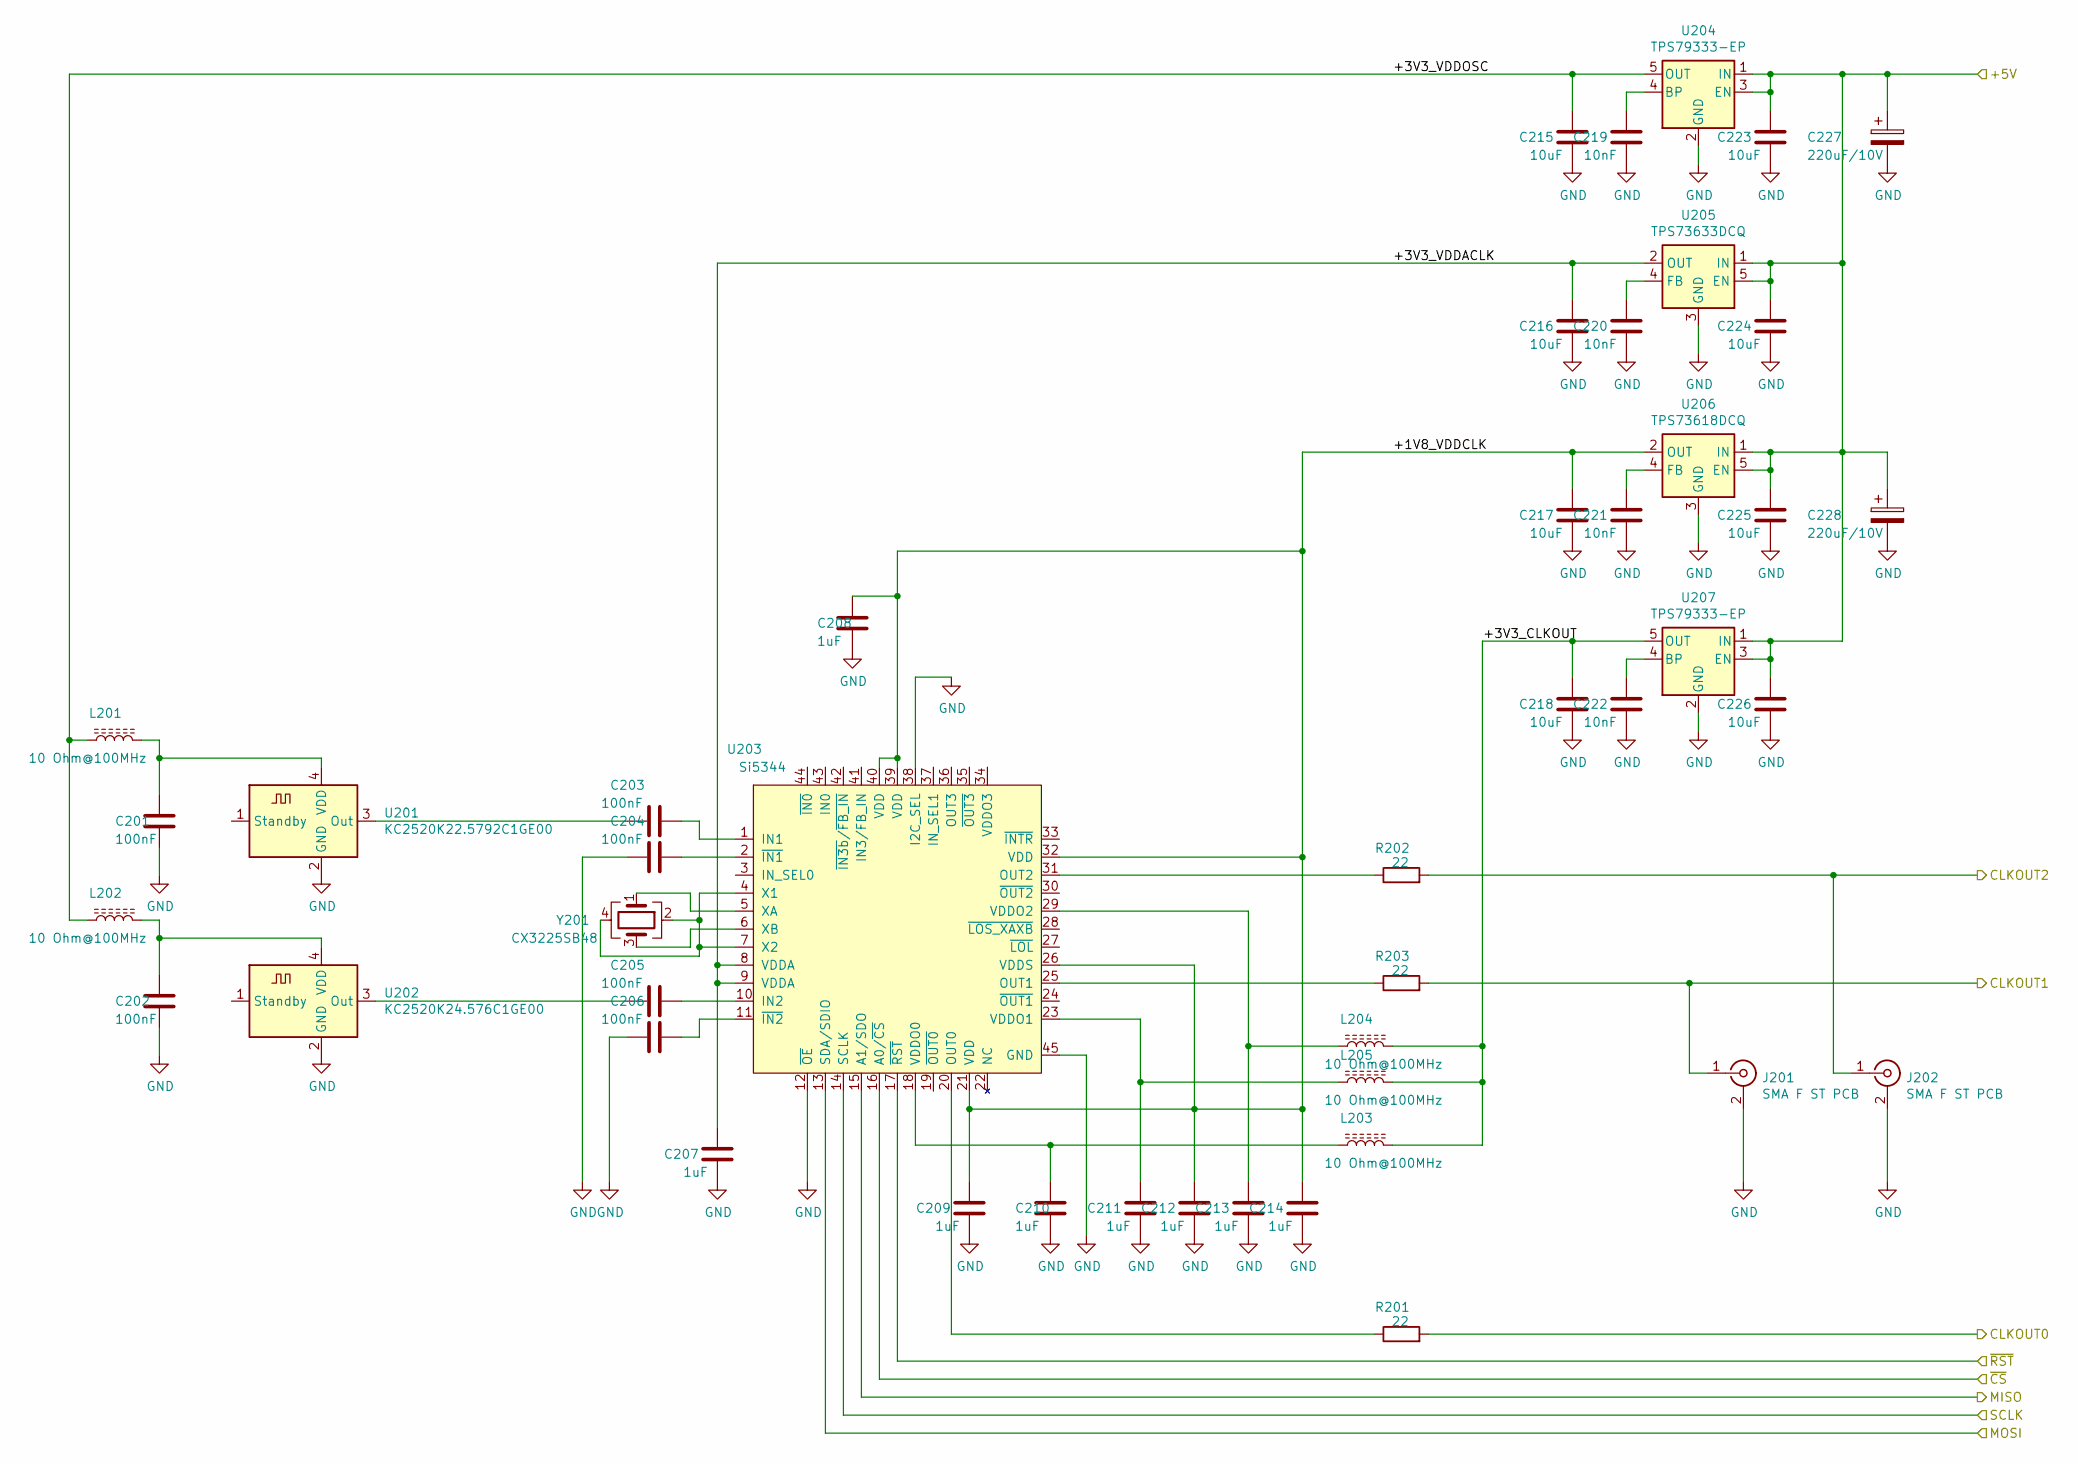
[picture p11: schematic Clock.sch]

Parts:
C201, C202, C203, C204, C205, C206: 100nF; C_0603_1608Metric
C207, C208, C209, C210, C211, C212, C213, C214: 1uF; C_0603_1608Metric
C215, C216, C217, C218, C223, C224, C225, C226: 10uF; C_0603_1608Metric
C219, C220, C221, C222: 10nF; C_0603_1608Metric
C227, C228: 220uF/10V; C_Elec_8x6.2
J201, J202: SMA F ST PCB; SMA_Amphenol_132134_Vertical
L201, L202, L203, L204, L205: 10 Ohm@100MHz; L_0805_2012Metric
R201, R202, R203: 22; R_0603_1608Metric
U201: KC2520K22.5792C1GE00; Oscillator_SMD_Abracon_ASDMB-4Pin_2.5x2.0mm
U202: KC2520K24.576C1GE00; Oscillator_SMD_Abracon_ASDMB-4Pin_2.5x2.0mm
U203: Si5344; QFN-44-1EP_7x7mm_P0.5mm_EP5.2x5.2mm
U204, U207: TPS79333-EP; SOT-23-5
U205: TPS73633DCQ; SOT-223-6_TabPin3
U206: TPS73618DCQ; SOT-223-6_TabPin3
Y201: CX3225SB48; Crystal_SMD_3225-4Pin_3.2x2.5mm

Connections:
/Clock/+1V8_VDDCLK: C208.1, C209.2, C212.2, C214.2, C217.2, U203.21 (VDD), U203.26 (VDDS), U203.32 (VDD), U203.39 (VDD), U203.40 (VDD), U206.2 (OUT)
/Clock/+3V3_CLKOUT: C218.2, L203.2, L204.2, L205.2, U207.5 (OUT)
/Clock/+3V3_VDDACLK: C207.2, C216.2, U203.8 (VDDA), U203.9 (VDDA), U205.2 (OUT)
/Clock/+3V3_VDDOSC: C215.2, L201.1, L202.1, U204.5 (OUT)
/Clock/+5V: C223.2, C224.2, C225.2, C226.2, C227.1, C228.1, U204.1 (IN), U204.3 (EN), U205.1 (IN), U205.5 (EN), U206.1 (IN), U206.5 (EN), U207.1 (IN), U207.3 (EN); also elsewhere on the board
/DACL_SCK: J202.1 (In), R202.2; also elsewhere on the board
/DACR_SCK: J201.1 (In), R203.2; also elsewhere on the board
/FPGA_SCK: R201.2; also elsewhere on the board
/MISO: U203.15 (A1/SDO); also elsewhere on the board
/MOSI: U203.13 (SDA/SDIO); also elsewhere on the board
/SCLK: U203.14 (SCLK); also elsewhere on the board
/~CLK_CS~: U203.16 (A0/~CS~); also elsewhere on the board
/~CLK_RST_: U203.17 (~RST~); also elsewhere on the board
GND: C201.2, C202.2, C204.2, C206.2, C207.1, C208.2, C209.1, C210.2, C211.1, C212.1, C213.1, C214.1, C215.1, C216.1, C217.1, C218.1, C219.1, C220.1, C221.1, C222.1, C223.1, C224.1, C225.1, C226.1, C227.2, C228.2, J201.2 (Ext), J202.2 (Ext), U201.2 (GND), U202.2 (GND), U203.12 (~OE~), U203.38 (I2C_SEL), U203.45 (GND), U204.2 (GND), U205.3 (GND), U206.3 (GND), U207.2 (GND); also elsewhere on the board
unnamed: C201.1, L201.2, U201.4 (VDD)
unnamed: C202.1, L202.2, U202.4 (VDD)
unnamed: C203.1, U203.1 (IN1)
unnamed: C203.2, U201.3 (Out)
unnamed: C204.1, U203.2 (~IN1~)
unnamed: C205.1, U203.10 (IN2)
unnamed: C205.2, U202.3 (Out)
unnamed: C206.1, U203.11 (~IN2~)
unnamed: C210.1, L203.1, U203.18 (VDDO0)
unnamed: C211.2, L205.1, U203.23 (VDDO1)
unnamed: C213.2, L204.1, U203.29 (VDDO2)
unnamed: C219.2, U204.4 (BP)
unnamed: C220.2, U205.4 (FB)
unnamed: C221.2, U206.4 (FB)
unnamed: C222.2, U207.4 (BP)
unnamed: R201.1, U203.20 (OUT0)
unnamed: R202.1, U203.31 (OUT2)
unnamed: R203.1, U203.25 (OUT1)
unnamed: U203.4 (X1), U203.7 (X2), Y201.2, Y201.4
unnamed: U203.5 (XA), Y201.1
unnamed: U203.6 (XB), Y201.3

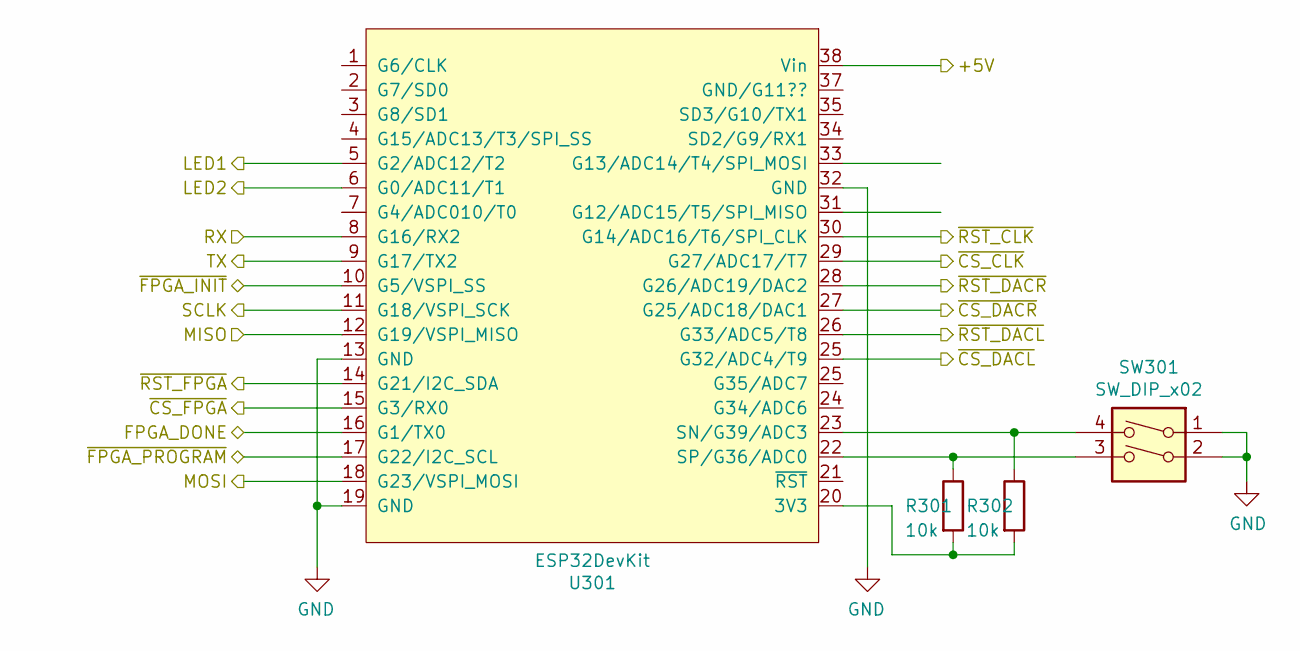
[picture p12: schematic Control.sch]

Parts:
R301, R302: 10k; R_0603_1608Metric
SW301: SW_DIP_x02; DIP-4_W7.62mm
U301: ESP32DevKit

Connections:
/Clock/+5V: U301.38 (Vin); also elsewhere on the board
/Control/LED1: U301.5 (G2/ADC12/T2); also elsewhere on the board
/Control/LED2: U301.6 (G0/ADC11/T1); also elsewhere on the board
/Control/~FPGA_INIT~: U301.10 (G5/VSPI_SS); also elsewhere on the board
/Control/~FPGA_PROGRAM~: U301.17 (G22/I2C_SCL); also elsewhere on the board
/Control/~RST_FPGA~: U301.14 (G21/I2C_SDA); also elsewhere on the board
/MISO: U301.12 (G19/VSPI_MISO); also elsewhere on the board
/MOSI: U301.18 (G23/VSPI_MOSI); also elsewhere on the board
/RX: U301.8 (G16/RX2); also elsewhere on the board
/SCLK: U301.11 (G18/VSPI_SCK); also elsewhere on the board
/SignalProcessing/DONE: U301.16 (G1/TX0); also elsewhere on the board
/TX: U301.9 (G17/TX2); also elsewhere on the board
/~CLK_CS~: U301.29 (G27/ADC17/T7); also elsewhere on the board
/~CLK_RST_: U301.30 (G14/ADC16/T6/SPI_CLK); also elsewhere on the board
/~DACL_CS~: U301.25 (G32/ADC4/T9); also elsewhere on the board
/~DACL_RST~: U301.26 (G33/ADC5/T8); also elsewhere on the board
/~DACR_CS~: U301.27 (G25/ADC18/DAC1); also elsewhere on the board
/~DACR_RST~: U301.28 (G26/ADC19/DAC2); also elsewhere on the board
/~FPGA_CS~: U301.15 (G3/RX0); also elsewhere on the board
GND: SW301.1, SW301.2, U301.13 (GND), U301.19 (GND), U301.32 (GND); also elsewhere on the board
unnamed: R301.1, SW301.3, U301.22 (SP/G36/ADC0)
unnamed: R301.2, R302.2, U301.20 (3V3)
unnamed: R302.1, SW301.4, U301.23 (SN/G39/ADC3)

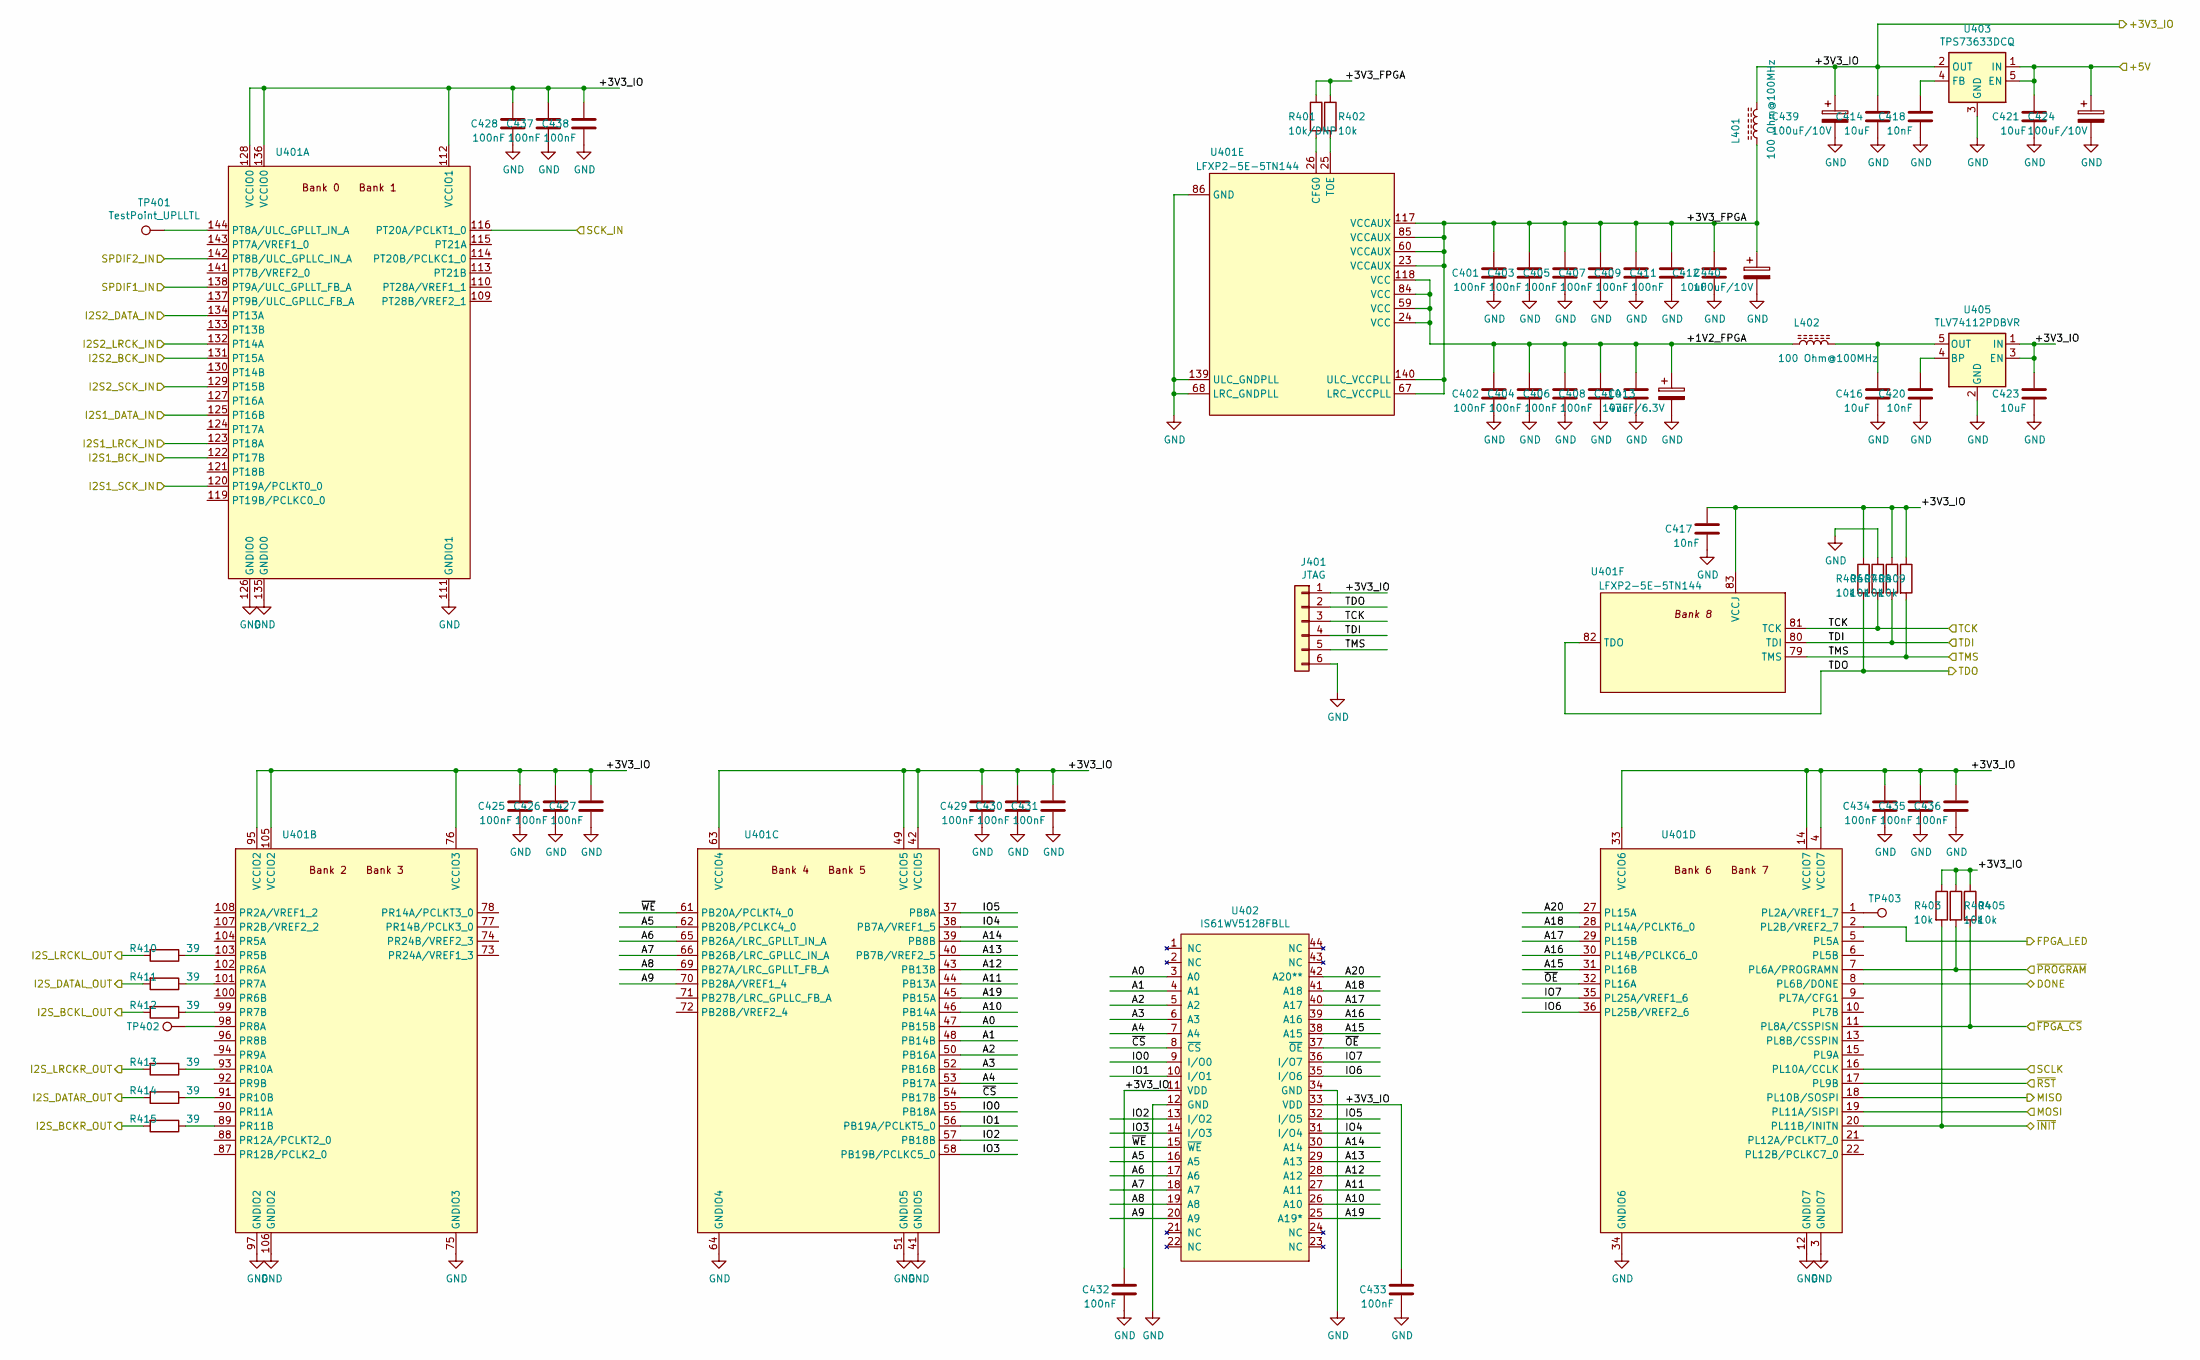
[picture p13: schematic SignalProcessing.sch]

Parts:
C401, C402, C403, C404, C405, C406, C407, C408, C409, C411, C425, C426, C427, C428, C429, C430, C431, C432, C433, C434, C435, C436, C437, C438: 100nF; C_0603_1608Metric
C410, C412, C414, C416, C421, C423: 10uF; C_0603_1608Metric
C413: 47uF/6.3V; CP_EIA-3528-12_Kemet-T
C417, C418, C420: 10nF; C_0603_1608Metric
C424, C439, C440: 100uF/10V; C_Elec_6.3x5.4
J401: JTAG; PinHeader_1x06_P2.54mm_Vertical
L401, L402: 100 Ohm@100MHz; L_0805_2012Metric
R401: 10k/DNP; R_0603_1608Metric
R402, R403, R404, R405, R406, R407, R408, R409: 10k; R_0603_1608Metric
R410, R411, R412, R413, R414, R415: 39; R_0603_1608Metric
TP401: TestPoint_UPLLTL; TestPoint_Pad_D1.0mm
TP402: TestPoint_free2; TestPoint_Pad_D1.0mm
TP403: TP_free1; TestPoint_Pad_D1.0mm
U401: LFXP2-5E-5TN144; TQFP-144_20x20mm_P0.5mm
U402: IS61WV5128FBLL; TSOP-II-44_10.16x18.41mm_P0.8mm
U403: TPS73633DCQ; SOT-223-6_TabPin3
U405: TLV74112PDBVR; SOT-23-5

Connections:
/Clock/+5V: C421.2, C424.1, U403.1 (IN), U403.5 (EN); also elsewhere on the board
/Control/~FPGA_INIT~: R403.2, U401.20 (PL11B/INITN); also elsewhere on the board
/Control/~FPGA_PROGRAM~: R404.2, U401.7 (PL6A/PROGRAMN); also elsewhere on the board
/Control/~RST_FPGA~: U401.17 (PL9B); also elsewhere on the board
/DACL_BCK: R412.2; also elsewhere on the board
/DACL_DATA: R411.2; also elsewhere on the board
/DACL_LRCK: R410.2; also elsewhere on the board
/DACR_BCK: R415.2; also elsewhere on the board
/DACR_DATA: R414.2; also elsewhere on the board
/DACR_LRCK: R413.2; also elsewhere on the board
/FPGA_SCK: U401.116 (PT20A/PCLKT1_0); also elsewhere on the board
/MISO: U401.18 (PL10B/SOSPI); also elsewhere on the board
/MOSI: U401.19 (PL11A/SISPI); also elsewhere on the board
/SCLK: U401.16 (PL10A/CCLK); also elsewhere on the board
/SignalProcessing/+1V2_FPGA: C402.2, C404.2, C406.2, C408.2, C410.2, C413.1, L402.1, U401.24 (VCC), U401.59 (VCC), U401.84 (VCC), U401.118 (VCC)
/SignalProcessing/+3V3_FPGA: C401.2, C403.2, C405.2, C407.2, C409.2, C411.2, C412.2, C440.1, L401.1, R401.1, R402.1, U401.23 (VCCAUX), U401.60 (VCCAUX), U401.67 (LRC_VCCPLL), U401.85 (VCCAUX), U401.117 (VCCAUX), U401.140 (ULC_VCCPLL)
/SignalProcessing/+3V3_IO: C414.2, C417.2, C423.2, C425.2, C426.2, C427.2, C428.2, C429.2, C430.2, C431.2, C432.2, C433.2, C434.2, C435.2, C436.2, C437.2, C438.2, C439.1, J401.1, L401.2, R403.1, R404.1, R405.1, R406.1, R408.1, R409.1, U401.4 (VCCIO7), U401.14 (VCCIO7), U401.33 (VCCIO6), U401.42 (VCCIO5), U401.49 (VCCIO5), U401.63 (VCCIO4), U401.76 (VCCIO3), U401.83 (VCCJ), U401.95 (VCCIO2), U401.105 (VCCIO2), U401.112 (VCCIO1), U401.128 (VCCIO0), U401.136 (VCCIO0), U402.11 (VDD), U402.33 (VDD), U403.2 (OUT), U405.1 (IN), U405.3 (EN); also elsewhere on the board
/SignalProcessing/A0: U401.47 (PB15B), U402.3 (A0)
/SignalProcessing/A1: U401.48 (PB14B), U402.4 (A1)
/SignalProcessing/A2: U401.50 (PB16A), U402.5 (A2)
/SignalProcessing/A3: U401.52 (PB16B), U402.6 (A3)
/SignalProcessing/A4: U401.53 (PB17A), U402.7 (A4)
/SignalProcessing/A5: U401.62 (PB20B/PCLKC4_0), U402.16 (A5)
/SignalProcessing/A6: U401.65 (PB26A/LRC_GPLLT_IN_A), U402.17 (A6)
/SignalProcessing/A7: U401.66 (PB26B/LRC_GPLLC_IN_A), U402.18 (A7)
/SignalProcessing/A8: U401.69 (PB27A/LRC_GPLLT_FB_A), U402.19 (A8)
/SignalProcessing/A9: U401.70 (PB28A/VREF1_4), U402.20 (A9)
/SignalProcessing/A10: U401.46 (PB14A), U402.26 (A10)
/SignalProcessing/A11: U401.44 (PB13A), U402.27 (A11)
/SignalProcessing/A12: U401.43 (PB13B), U402.28 (A12)
/SignalProcessing/A13: U401.40 (PB7B/VREF2_5), U402.29 (A13)
/SignalProcessing/A14: U401.39 (PB8B), U402.30 (A14)
/SignalProcessing/A15: U401.31 (PL16B), U402.38 (A15)
/SignalProcessing/A16: U401.30 (PL14B/PCLKC6_0), U402.39 (A16)
/SignalProcessing/A17: U401.29 (PL15B), U402.40 (A17)
/SignalProcessing/A18: U401.28 (PL14A/PCLKT6_0), U402.41 (A18)
/SignalProcessing/A19: U401.45 (PB15A), U402.25 (A19*)
/SignalProcessing/A20: U401.27 (PL15A), U402.42 (A20**)
/SignalProcessing/DONE: U401.8 (PL6B/DONE); also elsewhere on the board
/SignalProcessing/FPGA_LED: U401.2 (PL2B/VREF2_7); also elsewhere on the board
/SignalProcessing/I2S1_BCK_IN: U401.122 (PT17B); also elsewhere on the board
/SignalProcessing/I2S1_DATA_IN: U401.125 (PT16B); also elsewhere on the board
/SignalProcessing/I2S1_LRCK_IN: U401.123 (PT18A); also elsewhere on the board
/SignalProcessing/I2S1_SCK_IN: U401.120 (PT19A/PCLKT0_0); also elsewhere on the board
/SignalProcessing/I2S2_BCK_IN: U401.131 (PT15A); also elsewhere on the board
/SignalProcessing/I2S2_DATA_IN: U401.134 (PT13A); also elsewhere on the board
/SignalProcessing/I2S2_LRCK_IN: U401.132 (PT14A); also elsewhere on the board
/SignalProcessing/I2S2_SCK_IN: U401.129 (PT15B); also elsewhere on the board
/SignalProcessing/IO0: U401.55 (PB18A), U402.9 (I/O0)
/SignalProcessing/IO1: U401.56 (PB19A/PCLKT5_0), U402.10 (I/O1)
/SignalProcessing/IO2: U401.57 (PB18B), U402.13 (I/O2)
/SignalProcessing/IO3: U401.58 (PB19B/PCLKC5_0), U402.14 (I/O3)
/SignalProcessing/IO4: U401.38 (PB7A/VREF1_5), U402.31 (I/O4)
/SignalProcessing/IO5: U401.37 (PB8A), U402.32 (I/O5)
/SignalProcessing/IO6: U401.36 (PL25B/VREF2_6), U402.35 (I/O6)
/SignalProcessing/IO7: U401.35 (PL25A/VREF1_6), U402.36 (I/O7)
/SignalProcessing/SPDIF1_IN: U401.138 (PT9A/ULC_GPLLT_FB_A); also elsewhere on the board
/SignalProcessing/SPDIF2_IN: U401.142 (PT8B/ULC_GPLLC_IN_A); also elsewhere on the board
/SignalProcessing/TCK: J401.3, R407.2, U401.81 (TCK); also elsewhere on the board
/SignalProcessing/TDI: J401.4, R408.2, U401.80 (TDI); also elsewhere on the board
/SignalProcessing/TDO: J401.2, R406.2, U401.82 (TDO); also elsewhere on the board
/SignalProcessing/TMS: J401.5, R409.2, U401.79 (TMS); also elsewhere on the board
/SignalProcessing/~CS~: U401.54 (PB17B), U402.8 (~CS~)
/SignalProcessing/~OE~: U401.32 (PL16A), U402.37 (~OE~)
/SignalProcessing/~WE~: U401.61 (PB20A/PCLKT4_0), U402.15 (~WE~)
/~FPGA_CS~: R405.2, U401.11 (PL8A/CSSPISN); also elsewhere on the board
GND: C401.1, C402.1, C403.1, C404.1, C405.1, C406.1, C407.1, C408.1, C409.1, C410.1, C411.1, C412.1, C413.2, C414.1, C416.1, C417.1, C418.1, C420.1, C421.1, C423.1, C424.2, C425.1, C426.1, C427.1, C428.1, C429.1, C430.1, C431.1, C432.1, C433.1, C434.1, C435.1, C436.1, C437.1, C438.1, C439.2, C440.2, J401.6, R407.1, U401.3 (GNDIO7), U401.12 (GNDIO7), U401.34 (GNDIO6), U401.41 (GNDIO5), U401.51 (GNDIO5), U401.64 (GNDIO4), U401.68 (LRC_GNDPLL), U401.75 (GNDIO3), U401.86 (GND), U401.97 (GNDIO2), U401.106 (GNDIO2), U401.111 (GNDIO1), U401.126 (GNDIO0), U401.135 (GNDIO0), U401.139 (ULC_GNDPLL), U402.12 (GND), U402.34 (GND), U403.3 (GND), U405.2 (GND); also elsewhere on the board
unnamed: C416.2, L402.2, U405.5 (OUT)
unnamed: C418.2, U403.4 (FB)
unnamed: C420.2, U405.4 (BP)
unnamed: R401.2, U401.26 (CFG0)
unnamed: R402.2, U401.25 (TOE)
unnamed: R410.1, U401.103 (PR5B)
unnamed: R411.1, U401.101 (PR7A)
unnamed: R412.1, U401.99 (PR7B)
unnamed: R413.1, U401.93 (PR10A)
unnamed: R414.1, U401.91 (PR10B)
unnamed: R415.1, U401.89 (PR11B)
unnamed: TP401.1, U401.144 (PT8A/ULC_GPLLT_IN_A)
unnamed: TP402.1, U401.98 (PR8A)
unnamed: TP403.1, U401.1 (PL2A/VREF1_7)

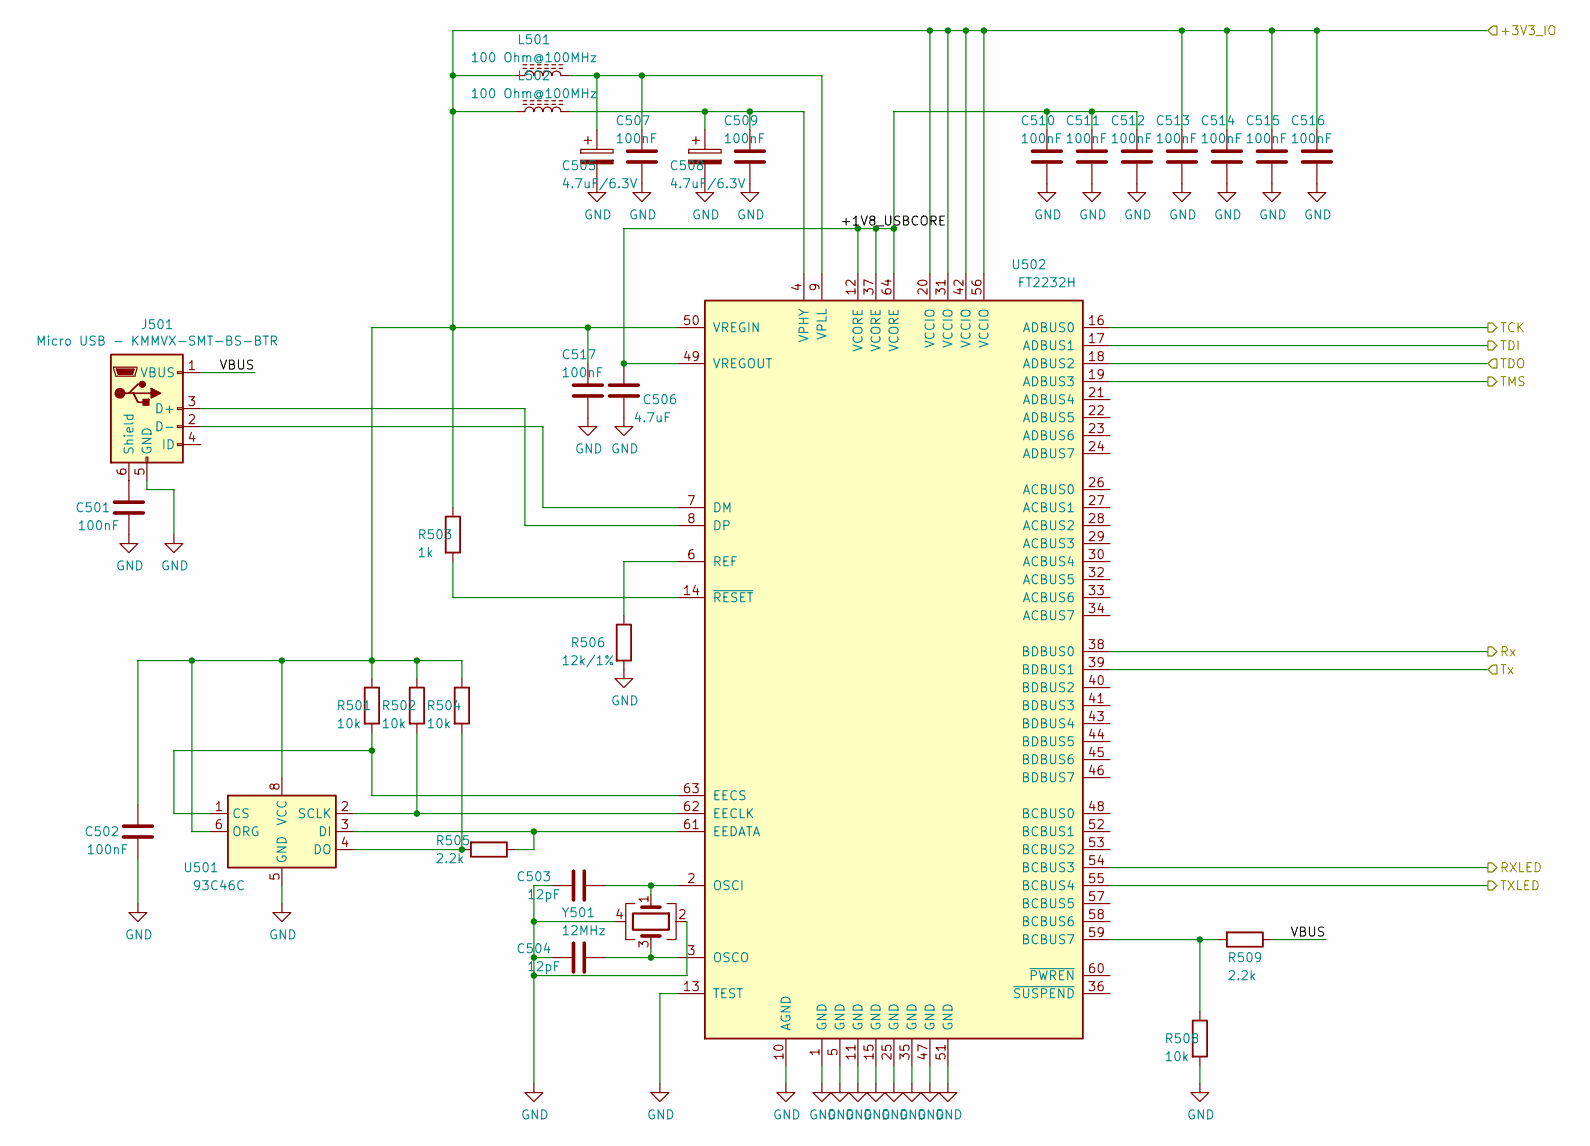
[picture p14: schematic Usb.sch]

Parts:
C501, C502, C507, C509, C510, C511, C512, C513, C514, C515, C516, C517: 100nF; C_0603_1608Metric
C503, C504: 12pF; C_0603_1608Metric
C505, C508: 4.7uF/6.3V; CP_EIA-3216-18_Kemet-A
C506: 4.7uF; C_0603_1608Metric
J501: Micro USB - KMMVX-SMT-BS-BTR; USB_MICRO_207A-BBA0-R
L501, L502: 100 Ohm@100MHz; L_0805_2012Metric
R501, R502, R504, R508: 10k; R_0603_1608Metric
R503: 1k; R_0603_1608Metric
R505, R509: 2.2k; R_0603_1608Metric
R506: 12k/1%; R_0603_1608Metric
U501: 93C46C; SOIC-8_3.9x4.9mm_P1.27mm
U502: FT2232H; LQFP-64_10x10mm_P0.5mm
Y501: 12MHz; Crystal_SMD_3225-4Pin_3.2x2.5mm

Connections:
/RX: U502.38 (BDBUS0); also elsewhere on the board
/SignalProcessing/+3V3_IO: C502.2, C513.1, C514.1, C515.1, C516.1, C517.1, L501.1, L502.1, R501.1, R502.1, R503.1, R504.1, U501.6 (ORG), U501.8 (VCC), U502.20 (VCCIO), U502.31 (VCCIO), U502.42 (VCCIO), U502.50 (VREGIN), U502.56 (VCCIO); also elsewhere on the board
/TX: U502.39 (BDBUS1); also elsewhere on the board
/Usb/+1V8_USBCORE: C506.1, C510.1, C511.1, C512.1, U502.12 (VCORE), U502.37 (VCORE), U502.49 (VREGOUT), U502.64 (VCORE)
/Usb/RXLED: U502.54 (BCBUS3); also elsewhere on the board
/Usb/TCK: U502.16 (ADBUS0); also elsewhere on the board
/Usb/TDI: U502.17 (ADBUS1); also elsewhere on the board
/Usb/TDO: U502.18 (ADBUS2); also elsewhere on the board
/Usb/TMS: U502.19 (ADBUS3); also elsewhere on the board
/Usb/TXLED: U502.55 (BCBUS4); also elsewhere on the board
/Usb/VBUS: J501.1 (VBUS), R509.1
GND: C501.1, C502.1, C503.1, C504.1, C505.2, C506.2, C507.2, C508.2, C509.2, C510.2, C511.2, C512.2, C513.2, C514.2, C515.2, C516.2, C517.2, J501.5 (GND), R506.2, R508.2, U501.5 (GND), U502.1 (GND), U502.5 (GND), U502.10 (AGND), U502.11 (GND), U502.13 (TEST), U502.15 (GND), U502.25 (GND), U502.35 (GND), U502.47 (GND), U502.51 (GND), Y501.2, Y501.4; also elsewhere on the board
unnamed: C501.2, J501.6 (Shield)
unnamed: C503.2, U502.2 (OSCI), Y501.1
unnamed: C504.2, U502.3 (OSCO), Y501.3
unnamed: C505.1, C507.1, L501.2, U502.9 (VPLL)
unnamed: C508.1, C509.1, L502.2, U502.4 (VPHY)
unnamed: J501.2 (D-), U502.7 (DM)
unnamed: J501.3 (D+), U502.8 (DP)
unnamed: R501.2, U501.1 (CS), U502.63 (EECS)
unnamed: R502.2, U501.2 (SCLK), U502.62 (EECLK)
unnamed: R503.2, U502.14 (~RESET)
unnamed: R504.2, R505.2, U501.4 (DO)
unnamed: R505.1, U501.3 (DI), U502.61 (EEDATA)
unnamed: R506.1, U502.6 (REF)
unnamed: R508.1, R509.2, U502.59 (BCBUS7)

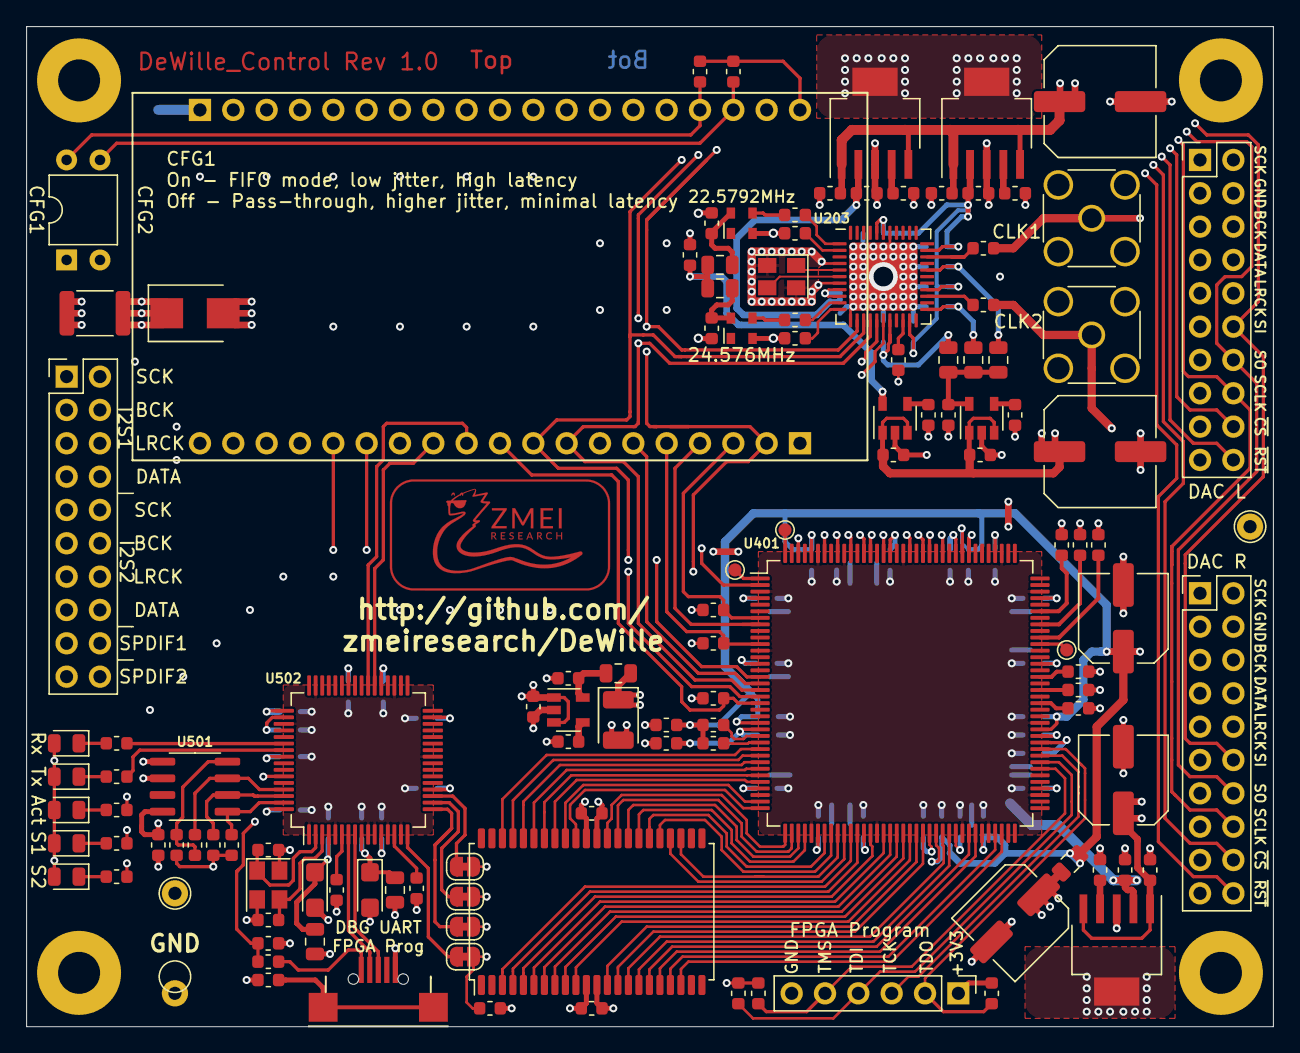
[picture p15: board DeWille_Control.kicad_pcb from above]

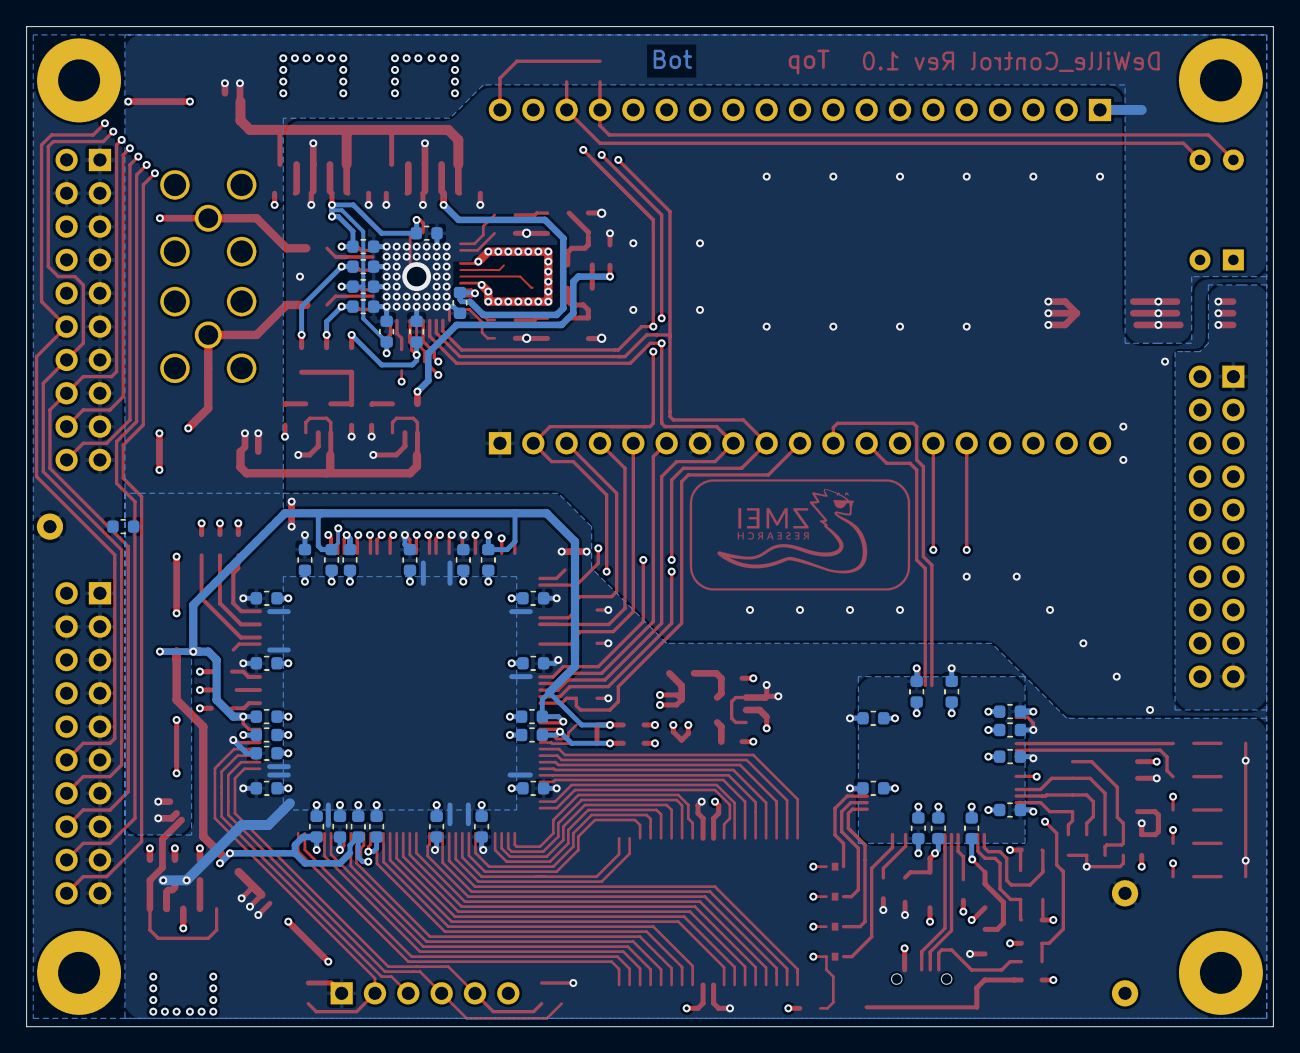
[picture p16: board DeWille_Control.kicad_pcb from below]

Board: 4 copper layers, 95.0 x 76.2 mm, 171 parts (43 on the bottom side), 149 nets.

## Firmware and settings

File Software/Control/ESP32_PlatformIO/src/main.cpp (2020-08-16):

/*==============================================================================
   DeWille ESP32 firmware

   Copyright 2020 Ivan Vasilev, Zmei Research Ltd.

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
   THE SOFTWARE IS PROVIDED "AS IS", WITHOUT WARRANTY OF ANY KIND, EXPRESS OR
   IMPLIED, INCLUDING BUT NOT LIMITED TO THE WARRANTIES OF MERCHANTABILITY,
   FITNESS FOR A PARTICULAR PURPOSE AND NONINFRINGEMENT. IN NO EVENT SHALL THE
   AUTHORS OR COPYRIGHT HOLDERS BE LIABLE FOR ANY CLAIM, DAMAGES OR OTHER
   LIABILITY, WHETHER IN AN ACTION OF CONTRACT, TORT OR OTHERWISE, ARISING FROM,
   OUT OF OR IN CONNECTION WITH THE SOFTWARE OR THE USE OR OTHER DEALINGS IN THE
   SOFTWARE.
  ============================================================================*/

//==============================================================================
//  Includes
//==============================================================================
#include <Arduino.h>

#include "logger.h"

#include <WString.h>
#include <pgmspace.h>

#include "webserver.h"

#include "si534x.h"
#include "pcm1792.h"

//==============================================================================
//  Defines
//==============================================================================
#define CMP_NAME                "Main"

#if CONFIG_FREERTOS_UNICORE
#define ARDUINO_RUNNING_CORE    0
#else
#define ARDUINO_RUNNING_CORE    1
#endif

#define   INIT_DO_HIGH(x)       { pinMode((x), OUTPUT); digitalWrite((x), HIGH); }
#define   INIT_DO_LOW(x)        { pinMode((x), OUTPUT); digitalWrite((x), LOW); }


//==============================================================================
//  Local types
//==============================================================================
// Function pointers for the pseudo-modules. Each module gets a separate task,
// in which 1) It's Init function is executed; 2) If init is OK, the Loop
// function is called  periodically until it returns != OK, after which, the
// task is deleted. Loop can also not return at all, but in this case, it needs
// to call delay/yield on it's own
typedef eStatus (*ModuleInitFn)(void * params);
typedef eStatus (*ModuleLoopFn)();

typedef struct _Module
{
    const char *    Name;
    ModuleInitFn    Init;
    ModuleLoopFn    Loop;
    uint32_t        Period;
    void *          Params;
    uint32_t        StackSize;
    uint8_t         Priority;   // Priority, with 3 (configMAX_PRIORITIES - 1)
                                // being the highest, and 0 being the lowest.
} Module;


//==============================================================================
//  Local function definitions
//==============================================================================
static eStatus blinkLoop();
static eStatus si534xLoop();


//==============================================================================
//  Local data
//==============================================================================
const Module Modules[] = {
    { "Logger",     LogInit,        LogLoop,    LOG_TASK_PERIOD,    NULL,   4096,   2 },
    { "Blink",      NULL,           blinkLoop,  0,                  NULL,   4096,   1 },
    { "Webserver",  WebserverInit,  NULL,       5,                  NULL,   4096,   1 },
    { "Si534x",     Si534xInit,     si534xLoop, 0,                  NULL,   4096,   1 },
    { "Pcm1792",    Pcm1792Init,    Pcm1792CheckDevice,   5000,     NULL,   4096,   1 }
};


//==============================================================================
//  Local functions
//==============================================================================
static eStatus blinkLoop()
{
    digitalWrite(DO_LED_1, HIGH);
    vTaskDelay(500/portTICK_PERIOD_MS);
    digitalWrite(DO_LED_1, LOW);
    vTaskDelay(500/portTICK_PERIOD_MS);

    //Log(eLogWarn, CMP_NAME, "Still alive!");

    return eOK;
}

static eStatus si534xLoop()
{
    const char * configList[10];
    uint8_t configCount;
    eStatus retVal = Si534xListConfigs(10, &configCount, configList);
    Log(eLogInfo, CMP_NAME, "Si534xListConfigs returned: %d, got %d configs", retVal, configCount);
    for (int i = 0; i < configCount; i++)
    {
        Log(eLogInfo, CMP_NAME, "config ID: %d, name: %s", i, configList[i]);
    }

    Si534xDumpStatus();
    retVal = Si534xSetConfig(1);

    Si534xDumpStatus();

    return eDONE;
}

static void setupHardware()
{
    // Hold all devices in reset
    INIT_DO_LOW(DO_nRST_FPGA);
    INIT_DO_HIGH(DO_nRST_DACR);
    INIT_DO_HIGH(DO_nRST_DACL);
    INIT_DO_HIGH(DO_nRST_CLK);

    // LED1 and LED2 off
    INIT_DO_HIGH(DO_LED_1);
    INIT_DO_HIGH(DO_LED_2);
}

static void moduleHost(void * param)
{
    eStatus retVal = eOK;
    const Module * const module = (const Module * const)param;

    if (NULL != module->Init)
    {
        retVal = module->Init(module->Params);
    }

    if (NULL != module->Loop)
    {
        while (eOK == retVal)
        {
            retVal = module->Loop();
            if (0 != module->Period)
            {
                vTaskDelay(module->Period / portTICK_PERIOD_MS);
            }
        }
    }
    // FreeRTOS will reclaim resources
    vTaskDelete(NULL);
}

static eStatus startModules()
{
    eStatus retVal = eOK;
    TaskHandle_t    taskHandle;

    for (int i = 0; i < ARRAY_SIZE(Modules); i++)
    {
        xTaskCreate(moduleHost,
                Modules[i].Name,
                Modules[i].StackSize,   // Stack size
                (void*)&Modules[i],
                Modules[i].Priority,
                &taskHandle);
        if (taskHandle == NULL)
        {
            Log(eLogCrit, CMP_NAME, "startModules: Error creating task for %s", Modules[i].Name);
            // Logger may not be working at that time!
            Serial.begin(115200);
            Serial.print("startModules: Error creating task for");
            Serial.println(Modules[i].Name);

            retVal = eFAIL;
        }
    }
    return retVal;
}

//==============================================================================
//  Exported functions
//==============================================================================

void setup()
{
    eStatus retVal = eOK;

    setupHardware();

    LogSetMinLevel(eLogInfo);

    retVal = startModules();

    //retVal = Pcm1792CheckDevice();
    //if (eOK == retVal)
    //{
    //    retVal = Pcm1792Init();
    //}

    //retVal = DewilleWebserverSetup();

}

// All tasks already started during setup()
void loop()
{

}

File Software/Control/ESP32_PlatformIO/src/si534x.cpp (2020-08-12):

/*==============================================================================
   DeWille ESP32 firmware

   Copyright 2020 Ivan Vasilev, Zmei Research Ltd.

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
   THE SOFTWARE IS PROVIDED "AS IS", WITHOUT WARRANTY OF ANY KIND, EXPRESS OR
   IMPLIED, INCLUDING BUT NOT LIMITED TO THE WARRANTIES OF MERCHANTABILITY,
   FITNESS FOR A PARTICULAR PURPOSE AND NONINFRINGEMENT. IN NO EVENT SHALL THE
   AUTHORS OR COPYRIGHT HOLDERS BE LIABLE FOR ANY CLAIM, DAMAGES OR OTHER
   LIABILITY, WHETHER IN AN ACTION OF CONTRACT, TORT OR OTHERWISE, ARISING FROM,
   OUT OF OR IN CONNECTION WITH THE SOFTWARE OR THE USE OR OTHER DEALINGS IN THE
   SOFTWARE.
  ============================================================================*/

//==============================================================================
//  Includes
//==============================================================================
#include <stdio.h>
#include <stdlib.h>

#include "si534x.h"
#include "si534x_regs.h"

#include "port.h"   // for PortGetTime/PortSleepMs

#include "../../Si5344_ClockBuilder/Si5344_RevD_DeWille01.h"

#include "logger.h"

#include "spi_mux.h"

//==============================================================================
//  Defines
//==============================================================================
#define CMP_NAME                "SI534x"
#define ALWAYS_SET_PAGE         false
#define SI534X_SETUP_TIME       1000    // time in ms to wait for config to be
                                        // applied


#define MAX_CONSECUTIVE_REGS    64  // maximal number of config registers to try
                                    // writing consecutively
// Si5342/44/45 commands - pg. 53 Si5345-44-42-D-RM.pdf
#define CMD_SET_ADDRESS         (uint8_t)0x0    // 000x xxxx
#define CMD_WRITE_DATA          (uint8_t)0x40   // 010x xxxx
#define CMD_READ_DATA           (uint8_t)0x80   // 100x xxxx
#define CMD_WRITE_INCREMENT     (uint8_t)0x60   // 011x xxxx
#define CMD_READ_INCREMENT      (uint8_t)0xa0   // 101x xxxx
#define CMD_WRITE_BURST         (uint8_t)0xe0   // 1110 0000

#define DATA_DUMMY              (uint8_t)0xA5
#define DEVICE_READY            (uint8_t)0xF0   // RM pg.182


//==============================================================================
//  Local types
//==============================================================================

//==============================================================================
//  Local data
//==============================================================================

static eSi534xType clkType = eSiTypeUnknown;
static bool initialized = false;
static uint8_t currentPage = 0xDE;

//static uint8_t buffer[32];      // adjust accordingly

//==============================================================================
//  Local functions
//==============================================================================

static bool isReady()
{
    bool retVal = false;

    // DEVICE_READY is accessible on every page
    uint8_t tmp[2] = { CMD_SET_ADDRESS, Reg_DeviceReady.address };
    SpiTransfer(eSpiDevCLK, &tmp[0], 2);

    tmp[0] = CMD_READ_DATA;
    tmp[1] = DATA_DUMMY;

    if (tmp[1] == DEVICE_READY)
    {
        retVal = true;
    }

    Log(eLogDebug, CMP_NAME, "isReady: %d", retVal);

    return retVal;
}

static eStatus setPage(uint8_t page)
{
    eStatus retVal = eOK;
    // Valid pages are 0-5 and 9, Si5345-44-42-D-RM pg. 81
    // However, there are also pg. A and pg. B - the same
    // Ref manual, pg. 122 and 123
    // And finally, ClockBuilderPro generates settings for 
    // page 8 as well.
    if (((0 <= page) && (page <= 5)) ||
        ((8 <= page) && (page <= 0xb)))
    {
        if ((page != currentPage) || ALWAYS_SET_PAGE)
        {
            // the page-setting address is accessible from every page
            uint8_t tmp[2];
            tmp[0] = CMD_SET_ADDRESS;
            tmp[1] = Reg_Page.address;
            SpiTransfer(eSpiDevCLK, &tmp[0], 2);

            tmp[0] = CMD_WRITE_DATA;
            tmp[1] = page;
            SpiTransfer(eSpiDevCLK, &tmp[0], 2);
            currentPage = page;
            Log(eLogDebug, CMP_NAME, "setPage: %d", page);
        }
    }
    else
    {
        Log(eLogWarn, CMP_NAME, "setPage: Tried setting invalid page %d", page);
        retVal = eINVALIDARG;
    }

    return retVal;
}

static eStatus readReg(const tSiReg& reg, uint8_t * buf, uint8_t bufferSize)
{
    eStatus retVal = eOK;
    uint8_t tmp[2];

    if ((NULL == buf) || (0 == bufferSize))
    {
        retVal = eINVALIDARG;
    }
    else if (bufferSize < reg.len)
    {
        retVal = eFAIL;
    }
    else
    {
        // Switch to  the correct page
        retVal = setPage(reg.page);
        if (eOK == retVal)
        {
            // Set address to start reading from
            tmp[0] = CMD_SET_ADDRESS;
            tmp[1] = reg.address;
            SpiTransfer(eSpiDevCLK, &tmp[0], 2);

            // Then read as many bytes as required
            for (int i = 0; i < reg.len; i++)
            {
                // needs to be set on each iteration as SpiTransfer overwrites the buffer
                tmp[0] = CMD_READ_INCREMENT;
                tmp[1] = DATA_DUMMY;
                SpiTransfer(eSpiDevCLK, &tmp[0], 2);
                buf[i] = tmp[1];
            }

            // everything below is for debug purposes
            char * printBuf = (char *)malloc(reg.len * 5);    // 0xXX,0xYY + zero termination

            if (NULL == printBuf)
            {
                retVal = eOUTOFMEMORY;
                Log(eLogError, CMP_NAME, "readReg: Memory allocation failed!");
            }
            else
            {
                // print the first byte
                sprintf(&printBuf[0], "0x%02X", buf[0]);
                for (int i = 1; i < reg.len; i++)
                {
                    // overwrite the null-termination of the previous sprintf
                    sprintf(&printBuf[((i - 1)*5) + 4], ",0x%02X", buf[i]);
                }

                Log(eLogDebug, CMP_NAME,
                    "readReg: Reading Si534x register: page: %d, address: 0x%02X, got: %s",
                    reg.page, reg.address, printBuf);

                free(printBuf);
            }
        }
    }

    return retVal;
}
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

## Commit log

2019-11-12 Clock generation mostly complete. Some inter-module connections fixed.
    [Clock.sch, Control.sch, DeWille.sch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]
2019-11-16 Remove galvanic isolator - too much jitter! Add USB interface for Debug and program purposes. Swith to Lattice FPGA
    [Clock.sch, Control.sch, DeWille.sch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]
2019-11-16 Split design on Base, Control and DAC boards
    [Clock.sch, Control.sch, DeWille.kicad_pcb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]
2019-11-17 Control board diagram complete at high level - Clock, USB, Control, Power and IO done. Remaining is FPGA pin assignment which will be done later to optimize board layout.
    [Clock.sch, Control.sch, DeWille.sch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]
2019-11-19 Provision for SPI Slave FPGA bitstream download. Switch RAM from x16 to x8 one.
    [Clock.sch, Control.sch, DeWille_Control.kicad_pcb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]
2019-11-22 Interim commit
    [Control.sch, DeWille_Control.kicad_pcb, DeWille_Control.sch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]
2019-11-23 Routing complete
    [Control.sch, DeWille_Control.kicad_pcb, DeWille_Control.sch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]
2019-11-24 Add source termination resistors to I2S output lines. Arrange top silk information.
    [DeWille_Control.kicad_pcb, DeWille_Control.sch, SignalProcessing.sch]
2019-11-24 Arrange bottom silk screen. Remove obsolete files.
    [DeWille_Control.kicad_pcb]
2019-11-24 Add some testpads. Fix +3V3_FPGA track mix-up after termination addition.
    [DeWille_Control.kicad_pcb, DeWille_Control.sch, SignalProcessing.sch]
2019-11-24 Add decoupling cap between +5V and GND
    [DeWille_Control.kicad_pcb, DeWille_Control.sch, SignalProcessing.sch]
2019-11-26 Swap BCK and LRCK outputs. Misc small touch-ups on the board
    [DeWille_Control.kicad_pcb, DeWille_Control.sch, SignalProcessing.sch]
2019-11-26 Add PCM1794 DAC board.
    [PCM1794.kicad_pcb, PCM1794.sch, PCM1794_DAC.sch]
2019-11-27 Send for manufacturing Control and DAC1794 boards.
    [PCM1794.kicad_pcb]
2019-12-03 Add Base board schematic
    [DeWille_Base.kicad_pcb, DeWille_Base.sch, Power_Supply.sch]
2019-12-09 Base schematic complete
    [DeWille_Base.kicad_pcb, DeWille_Base.sch, Isolator.sch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]
2019-12-29 Check-in of misc. sch changes to Base
    [Isolator.sch, Power_Supply.sch]
2020-01-08 Add Changes.txt, listing future changes to the schematic and boards Finish up Base board routing
    [DeWille_Base.kicad_pcb, DeWille_Base.sch, Isolator.sch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]
2020-02-06 Updated Changes.md after Base Board test construction
2020-02-06 Add small comment for GND poly on DAC board
2020-02-06 Add information on Base Board regulator test. Trying to include some pictures as well.
2020-03-15 Add PlatformIO project for ESP32
2020-03-16 Add mention of ESP32 powering
2020-03-17 Fix indent and braces
    [main.cpp]
2020-03-17 Fix BlinkTask stack size so that the system actually starts.
    [main.cpp]
2020-03-24 Add notes about UART0 pin usage and Rx/Tx LEDs
2020-03-24 Switch logging to FT2232 UART and make it work
2020-03-28 Implement correct register reading & debug output
    [si5344.cpp, spi.cpp]
2020-03-28 Add some comments on Si534x driver
2020-03-28 Rename Si5344->Si534x to indicate that it's a generic driver. Move register definitions to si5344_regs.h as not to clutter the main code
2020-03-28 Implement device ID reading
2020-03-29 Move Software/ESP32/DeWille_PIO -> Software/Control/ESP32_PlatformIO Add ClockBuilder project and output for Si5344.
2020-03-30 Add some remarks on the Clock circuit
2020-04-04 Fix some issues in writeBuffer
    [main.cpp, si534x.cpp]
2020-04-04 Rename spi.[h/cpp] => spi_mux.[h/cpp], otherwise spi.h<=>SPI.h causes issues on case non-sensitive systems.
    [si534x.cpp, spi_mux.cpp]
2020-04-05 Bump SPI speed to 500kHz
2020-04-05 Fix an error that prevented properly setting configuration - it always wrote to page 0. Allowed page 8 to be accessed as well - ClockBuilderPro generates values for it. Add more debug output
    [main.cpp, si534x.cpp]
2020-08-05 Style a little the web interface page with Milligram
2020-08-16 Add FPGA passthrough sample project.

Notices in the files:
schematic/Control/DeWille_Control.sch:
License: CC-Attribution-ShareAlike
